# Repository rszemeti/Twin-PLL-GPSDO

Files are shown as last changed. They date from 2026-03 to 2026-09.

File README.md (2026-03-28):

# Twin PLL GPSDO

A dual-output GPS-disciplined reference project for Raspberry Pi Pico 2 (RP2350), with:
- Firmware for GPSDO control + PLL programming
- A desktop configuration tool (Windows-friendly)
- A PCB with 2 ADF4351's, GPS module and all the interface bits

## Who this is for
If you need a stable, GPS locked signal source for injection locking 1 or 2 crystal oscillators, or at a push a directly synthesised carrier up to 4.4 GHz.  

It has the advantage over some other units in that the two outputs are truly independently programmable. If you have a microwave transverter for example that needs injection locking and then a 144 to 28MHz converter, you often find that many units only allow the second output to be a fraction of the primary output, which may not produce thw 116 MHz you need. This unit has 2 synthesisers each of which can be programmed as desired.

## Features
- **Output 1 / Output 2 PLL**  Truly indpendent of each other
- **10MHz Auxilliary Output**  For driving other items, eg main radio.
- **Persistent settings** (ADF register writes are auto-committed to EEPROM)
- **Live status LEDs** (GPS fix/lock, satellites, DOP, alarm, lock states)
- **Windows configuration tool** with Main/Details/Tuning/About tabs

## RF output notes
- **Two outputs are fully independent**: each PLL output has its own register set and can be tuned separately.
- **Frequency range**: any frequency within the ADF4351 synthesizer output range is supported in software (approximately **34.375 MHz to 4.4 GHz**).
	- Practical usable range depends on your board layout, output network, filtering, and measurement method.
- **Resolution / step size**:
	- In **Integer-N**, tuning is quantized by $f_{PFD}/\text{OUTDIV}$.
	- With default settings (10 MHz ref, R=5, so $f_{PFD}=2$ MHz), Integer-N step is $2\text{ MHz}/\text{OUTDIV}$ (for example, 62.5 kHz at OUTDIV=32).
	- In **Fractional-N**, finer step sizes are possible (GUI default channel spacing is 1 Hz), but with fractional spurs/tradeoffs.
- **Phase-noise tradeoff**:
	- **Integer-N** is generally preferred for best close-in noise / cleaner spectrum when an exact frequency is possible.
	- **Fractional-N** gives finer frequency placement when exact Integer-N is not available, but may increase spur content.
- **Intended use guidance**:
	- Phase noise is typically **good enough for injection-locking crystal multipliers**.
	- It may **not** be good enough for all **direct multiplication** chains, depending on your multiplier stages and phase-noise budget.

## Repository layout
- `firmware/` – PlatformIO project for Pico 2
- `monitor/` – Python GUI configuration tool app
- `.github/workflows/` – release build automation
- `REFERENCE_LOCKING_README.md` – technical notes on GPS reference locking, PIO timing, interrupts, and timing/error budget

## Quick start (recommended)
### 1) Download a Release
From GitHub Releases, download:
- `Twin-PLL-GPSDO-<tag>.uf2` (firmware)
- `TwinPLLGPSDOMonitor-<tag>.exe` (Windows configuration tool)

### 2) Flash firmware (`.uf2`)
1. Put Pico 2 into BOOTSEL mode.
2. Copy the `.uf2` file to the mounted RP drive.
3. Board reboots automatically.

### 3) Run the configuration tool (`.exe`)
1. Start `TwinPLLGPSDOMonitor-<tag>.exe`.
2. Select COM port and click **Connect**.
3. Use **Set O/P 1** / **Set O/P 2** to configure outputs.

---

## Build from source
## Firmware
Prerequisites:
- Python 3.11+
- PlatformIO

Commands:
```bash
cd firmware
python -m platformio run
```
Upload (example COM port):
```bash
python -m platformio run -t upload --upload-port COM7
```

## Configuration tool (Python)
Prerequisites:
- Python 3.11+

Commands:
```bash
cd monitor
python -m venv .venv
.venv\Scripts\activate
pip install -r requirements.txt
python gpsdo_monitor.py
```

## Configuration tool usage notes
- **Main tab**: front-panel style status + output frequencies + output set buttons
- **Details tab**: logs, decoded registers, DAC/state details
- **About tab**: project links and author links

The configuration tool supports JSON command send for advanced/manual control.

## Persistence behavior
When a PLL/program command is applied:
- Registers are staged
- EEPROM auto-commit is performed in firmware
- On success, firmware emits a success event and the configuration tool shows **Device Updated**

## Releases and updates
On published release, GitHub Actions builds and attaches:
- Firmware UF2
- Configuration tool one-file EXE

So most users can update without local toolchains.

## Troubleshooting
- **Configuration tool cannot connect**: verify correct COM port and close other serial tools.
- **No lock / unstable GPS**: verify antenna visibility and allow warm-up time.
- **Upload issues on Windows**: retry BOOTSEL entry and ensure USB cable supports data.

## Author / links
- Robin Szemeti, G1YFG
- QRZ: https://www.qrz.com/db/G1YFG
- Blog: https://g1yfg.blogspot.com/
- Project repo: https://github.com/rszemeti/Twin-PLL-GPSDO

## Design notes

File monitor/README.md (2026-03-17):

GPSDO Configuration Tool

A minimal PySide6 GUI configuration tool that connects to the device over serial, parses JSON status lines, and displays key fields.

Full software manual:
- See `docs/MONITOR_USER_MANUAL.md` for complete usage, workflows, and troubleshooting.

Setup

To configure the unit, a simple GUI is available as a pre-built Windows .exe file Just download, connect your device over USB and run the program. You can configue the two fully independent outputs directly from the program. 

Updating the software on the unit itself is simply a question of powering it up ovr USB with the "reset" button pressed down and dragging a new .uf2 firmware file onto the folder that appears on your desktop.

Advanced

The adventurous may prefer to download the Python GUI sourcecode and run the GUI from its native Python source.

python -m venv .venv
.venv\Scripts\activate
pip install -r requirements.txt

Run

python gpsdo_monitor.py

Usage

- Select serial port and press Connect.
- The configuration tool displays firmware version, peripheral states, DAC value, ADF lock states, and logs raw/non-JSON lines.
- Send JSON commands from the **Advanced** tab send box (e.g. {"cmd":"dac","value":2048}).
- Use **Set PLL1 Register** or **Set PLL2 Register** to enter a target frequency and apply generated ADF4351 registers; popups preload from decoded live register values when available (otherwise fallback defaults are 10 MHz ref, R=5).
- Popup **Synth mode** options:
	- **Auto**: use Integer-N when exact, otherwise use Fractional-N.
	- **Integer-N only**: force integer synthesis.
	- **Fractional-N only**: force fractional synthesis for closest frequency.
- Popup **RF output power** lets you choose ADF4351 output power (-4, -1, +2, +5 dBm setting).
- Popup **Noise mode** lets you choose **Low noise** or **Low spur** register mode.
- Popup **Charge pump current** lets you choose the ADF4351 CP current code (0.31 mA to 5.00 mA).
- The firmware now auto-saves ADF registers to EEPROM when `program` is issued, so settings persist across reboot without a separate save step.
- **Discipliner Control (Advanced)** (Advanced tab) lets you read/apply runtime `avg_window_s`, `P gain`, and `I gain` via firmware JSON command `disc_ctrl`.
- Preset buttons (**Slow**, **Normal**, **Fast**) provide one-click loop tuning and immediately apply those values.
- Applied discipliner settings are persisted in firmware and restored after reboot.
- **Step Response...** in **Discipliner Control (Advanced)** opens a test tool that can run a timed DAC step, temporarily increase telemetry rate to 1 Hz, capture response samples, and export CSV.

ADF4351 register helper

- `adf4351_registers.py` contains a reusable `ADF4351RegisterCalculator` class.
- Use `solve(target_hz)` to generate `R0..R5` values from a reference/config.
- Use `decode_registers(regs, ref_hz)` and `verify_target(...)` to validate any existing register set before programming hardware.
- This is intended to avoid trusting unverified register words from external tools.

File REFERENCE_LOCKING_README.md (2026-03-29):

# Reference Locking Technical Notes

This is the technical companion to the main README. It describes how the
firmware actually locks the 10 MHz OCXO to GPS and what all the pieces do.

## 1) What the loop does

The whole point of the disciplining loop is to keep a local 10 MHz OCXO
tightly on frequency, steered by GPS 1PPS. Once the OCXO is disciplined,
it clocks both ADF4351 synthesisers.

In broad strokes:

1. Detect each GPS 1PPS rising edge.
2. Count how many 10 MHz cycles occurred during that one-second window.
3. Compute the integer count error: `edgesThisSec − 10,000,000`.
4. Keep a rolling ring buffer of the last N seconds of integer count
   errors and maintain a running sum.
5. Every second, divide the windowed sum by N to get the average count
   error in Hz (as a double), and feed that to the integrator which
   nudges the DAC (OCXO EFC voltage).
6. Only declare "locked" once the DAC output has been stable (not moving
   much) for long enough to be credible.

Here is the signal flow through the loop:

```mermaid
flowchart TD
    GPS[GPS 1PPS] --> PPS[PIO PPS capture ISR]
    OCXO[10 MHz OCXO] --> EDGE[PIO edge counter]
    EDGE --> PPS

    PPS --> OBS[Per-second observables
pulse count · integer count error Hz]

    OBS --> RING[Integer ring buffer
running sum of count errors]
    RING --> AVG[Average count error
windowSum / N  →  double Hz]
    AVG --> INT[Integrator
DAC -= gain × avg count error]
    INT --> DAC[DAC / EFC]
    DAC --> OCXO

    AVG --> LOCK[Lock detector
DAC stability over 60 s window]
    LOCK --> STATE[ACQUIRING / LOCKED / HOLDOVER]
    STATE -.-> INT

    EEPROM[Saved DAC from EEPROM] -.-> INT
```

---

## 2) How the measurement works

### 2.1 PPS capture

A PIO state machine watches the GPS 1PPS line. When it sees a rising
edge it fires `PIO0_IRQ_0`, which triggers the edge-counter snapshot
described below.

**Zero-jitter capture.** Because the PIO hardware reacts to the pin
within one PIO clock cycle (~6.67 ns at 150 MHz), no CPU interrupt
latency is involved in the timing-critical capture. A conventional ISR
would suffer variable delay while the CPU finishes its current
instruction, saves context, and vectors to the handler — this jitter
can easily be tens to hundreds of nanoseconds and would directly
corrupt the edge count. The PIO approach eliminates this entirely: the
state machine runs independently of the CPU, so the capture is
cycle-exact regardless of what the CPU is doing. Any count variability
observed is therefore real oscillator behaviour (thermal drift, EFC
settling, etc.) or GPS 1PPS edge quality, not measurement artefact.

We trust the GPS 1PPS to *be* one second — GPS 1PPS accuracy is
typically ±30 ns, which is far better than anything we could measure
on-chip. So the gate interval is simply one second by definition, and
the edge count over that gate *is* the OCXO frequency in Hz. No
division by a measured interval is needed or done.

### 2.2 Counting 10 MHz edges — the "counter around zero" model

The easiest way to think about the frequency measurement is this:

Imagine a virtual counter that starts at zero. Every rising edge of the
10 MHz OCXO **subtracts 1**. Every GPS 1PPS pulse **adds 10,000,000**.
If the oscillator is running at exactly 10 MHz, the counter stays at
zero — exactly 10 million edges arrive between each PPS, and the add
cancels the subtract perfectly. If the OCXO is running a little fast,
more than 10 million edges pile up and the counter drifts negative. If
it's a bit slow, fewer edges arrive and the counter drifts positive.

The value in the counter at any moment is the accumulated frequency
error in units of 10 MHz cycles. Over a multi-second window, summing
N one-second residuals gives the same number that a single free-running
counter would have reached — no edges are missed or double-counted, so
the two views are mathematically identical.

> **Implementation note:** the firmware doesn't literally maintain a
> running accumulated counter. Instead, a PIO state machine decrements
> its X register on every 10 MHz rising edge, and the PPS ISR snapshots
> X each second to compute the per-second delta
> (`edgesThisSec = prevX − currentX`). The one-second residual is then
> just `edgesThisSec − 10,000,000`. These integer residuals are stored
> in a ring buffer with a windowed `int64_t` running sum (bounded by
> window size × max per-second error, not an unbounded accumulation).
> The average over the window (`sum / N` as a `double`) is what feeds
> the integrator. The per-second unsigned subtraction of X handles
> 32-bit wrap correctly, and the windowed sum avoids any concern about
> unbounded growth, while preserving sub-ppb precision through the
> entire path.

From the per-second edge count, the frequency error is simply:

$$
error_{Hz} = N_{edges} - 10{,}000{,}000
$$

Because the PPS gate *is* one second, the edge count *is* the frequency
in Hz — no division required. The control loop works entirely in Hz
(integer count errors averaged to a `double`). A ppb value is also
computed for telemetry display but is **not** part of the control path:

$$
error_{ppb} = \frac{error_{Hz}}{10{,}000{,}000} \cdot 10^9 = error_{Hz} \times 100
$$

A **sanity gate** rejects any reading where the error exceeds ±50 kHz
(±0.5%). This catches partial first-second counts after a warm reset
(the PIO counter starts mid-PPS period and gets a nonsense edge count)
and cold OCXO startup where the crystal hasn't reached full amplitude
yet. Rejected readings are marked invalid so they never reach the
rolling average, the integrator, or the lock detector.

---

## 3) The control loop

The firmware maintains a rolling ring buffer of per-second **integer**
count errors (`edgesThisSec − 10,000,000`). A running `int64_t` sum
traces the ring so re-scanning is never needed. Every second, the
windowed sum is divided by the number of samples to produce an average
count error in Hz (as a `double`), and that value is passed to the
discipliner.

By keeping everything as exact integers until the final division, no
floating-point quantisation can create a dead zone — a single extra
edge in 128 seconds (0.0078 Hz) is faithfully represented.

The discipliner is a pure integrator (no proportional term). It adjusts
the DAC by `i_gain × avg_count_error` each second, where the averaging
window acts as a jitter filter without affecting the integrator's gain
units (DAC counts per Hz-error per update).

The loop runs in two modes:

- **Acquiring** — uses the base window (`DISC_AVERAGE_SECS`, default
  16 s) with the full I gain (`DISC_I_GAIN`, default 5.0) for fast
  pull-in.
- **Locked** — multiplies the window by `DISC_AVG_LOCKED_MULTIPLY`
  (currently ×4, giving 64 s) and reduces the gain by
  `DISC_I_GAIN_LOCKED_RATIO` (currently ×0.5, giving effective 2.5).
  Both changes happen simultaneously when lock is declared. The longer
  window plus the lower gain together narrow the loop bandwidth
  considerably, so normal 1PPS jitter doesn't keep jiggling the DAC.

When transitioning from ACQUIRING to LOCKED, the ring buffer and running
sum are zeroed so the locked-mode window starts clean without stale
pull-in residuals.

If lock is lost the short window and full gain kick back in.

On power-up the firmware reads the last-known DAC value from EEPROM and
seeds the integrator with it, so the OCXO starts very close to where it
left off rather than hunting from the middle of the DAC range.

The DAC output is hard-clamped to `DAC_MIN..DAC_MAX` so the integrator
can never rail.

### State machine

| State | Meaning |
|---|---|
| WARMUP | Waiting for GPS fix and initial settling |
| ACQUIRING | Loop is running, not yet meeting lock criteria |
| LOCKED | Error is small and DAC has settled — full lock |
| HOLDOVER | GPS lost, DAC is frozen at last good value |
| FREERUN | No GPS available, running open-loop |

---

## 4) Telemetry

The firmware sends two kinds of JSON messages over the serial link.

**OCXO event** (every second) — carries the raw measurement:
`pulse_count`, `measured_hz`, `freq_error_ppb`.

**Status** (periodic) — carries the full system snapshot: GPS fix,
DAC value, ADF lock-detect states, discipliner state, plus averaging
visibility fields (`disc_avg_window_s`, `disc_count_err`,
`disc_avg_count_err`, `count_err_sum`) so the monitor app can show
what the loop is doing.

---

## 5) Timing resolution

The PIO edge counter runs at the system clock (150 MHz, ~6.67 ns per
tick), but that's just the speed at which PIO executes its instructions
— the actual measurement resolution comes from counting complete 10 MHz
edges over a one-second gate. The gate itself is GPS 1PPS, which we
trust to be exactly one second (GPS 1PPS is accurate to ~30 ns).

So the frequency resolution is ±1 Hz per single-second gate (one edge
more or less), and averaging over several seconds smooths that further.

---

## 6) Why PIO edge counting?

Earlier firmware versions tried various approaches. The current PIO
counting method won out because it:

- counts every single 10 MHz edge without burning CPU time,
- avoids per-edge interrupts entirely (PIO does it in hardware),
- gives a clean integer count each second,
- pairs naturally with multi-second averaging for sub-ppb control.

---

## 7) ADF lock detect

The two ADF4351 PLLs have their own lock-detect pins (`ADF1_LD_PIN`,
`ADF2_LD_PIN`). These are read directly by the firmware and drive the
status LEDs, alarm logic, and the lock fields in telemetry JSON. They
are independent of the OCXO disciplining lock — they tell you whether
each synthesiser PLL is happy with its own loop.

---

## 8) How lock detection actually works

Frequency-error readings are inherently noisy — GPS 1PPS jitter can
produce occasional outliers of ±1300 ppb (±13 Hz) even when the OCXO is
perfectly stable. Trying to judge lock from the frequency error alone
turns out to be unreliable because those outliers poison any simple
threshold or average.

What *does* tell us whether the loop has converged is the DAC output.
When the integrator has found the right EFC voltage, the DAC value
stops moving — it just sits there, with small corrections that don't
add up to much. If the OCXO is genuinely drifting, the DAC has to
chase it and the value trends steadily in one direction.

The firmware keeps a ring buffer of the last 60 per-second DAC
snapshots and looks at the range (max − min) over that window:

- **Lock is entered** when the DAC range over 60 seconds is
  ≤ `DISC_LOCK_DAC_RANGE_ENTER` (currently 30 counts) and the DAC is
  not railed at `DAC_MIN` or `DAC_MAX`.
- **Lock is dropped** when the range exceeds
  `DISC_LOCK_DAC_RANGE_EXIT` (currently 50 counts).

The hysteresis between the enter and exit thresholds prevents the state
from flickering on borderline noise.

The lock buffer is only populated while the discipliner is in ACQUIRING
or LOCKED state — during FREERUN or WARMUP a constant DAC value would
otherwise fill the buffer and falsely declare lock. If lock is lost the
buffer is reset so the full 60-second dwell is required again.

Because the buffer must be full (60 seconds of stable DAC data) before
lock is even considered, this naturally prevents premature lock on cold
start or warm restart — the loop has to have converged and settled for
a solid minute before the firmware will claim it's locked.

---

## 9) Quick reference

| What | How |
|---|-----|
| PPS edge detection | PIO state machine, cycle-exact hardware capture (no ISR jitter) |
| Frequency measurement | PIO edge count of 10 MHz per 1PPS gate |
| Error signal | Integer count error per second → ring buffer → average (double Hz) |
| Control update rate | Every second (rolling average) |
| Loop type | Pure integrator (no P term), gain in DAC counts per Hz-error |
| I gain | Acquiring: 5.0, Locked: 2.5 (×0.5 ratio) |
| Averaging window | Acquiring: 16 s, Locked: 16 × 4 = 64 s |
| DAC persistence | Saved to EEPROM, restored on restart |
| Lock criteria | 60 s DAC ring buffer: range ≤ 30 counts to enter, > 50 to exit |
| Gain management | Acquiring: full gain + base window; Locked: gain ×0.5 + window ×4 (both applied simultaneously) |
| Zero-on-lock-entry | Ring buffer cleared on ACQUIRING → LOCKED transition |

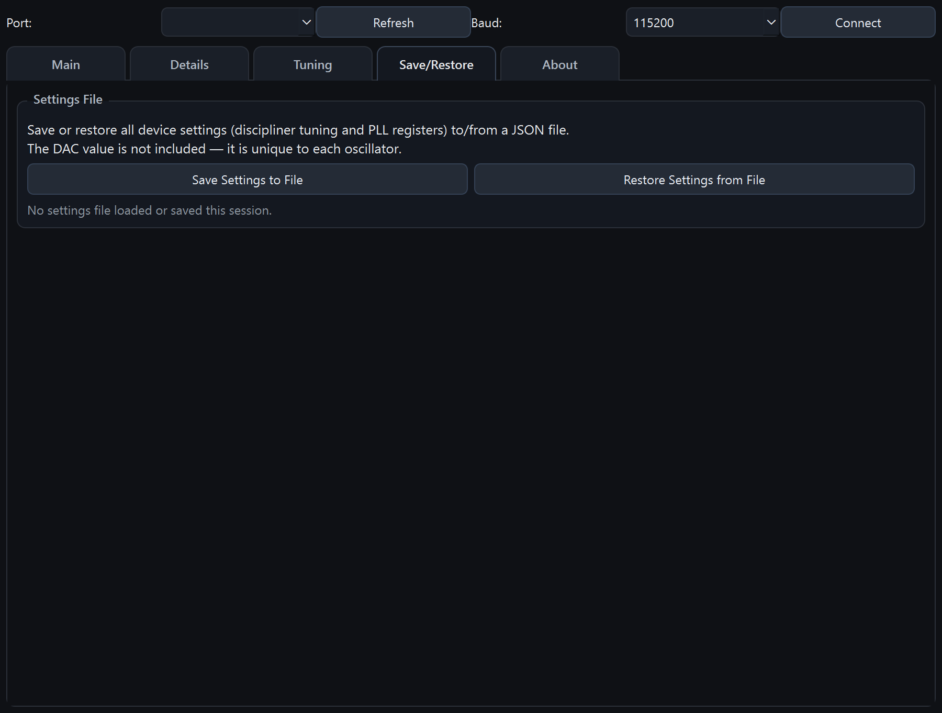
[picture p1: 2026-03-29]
docs/screenshots/07-saverestore-live.png

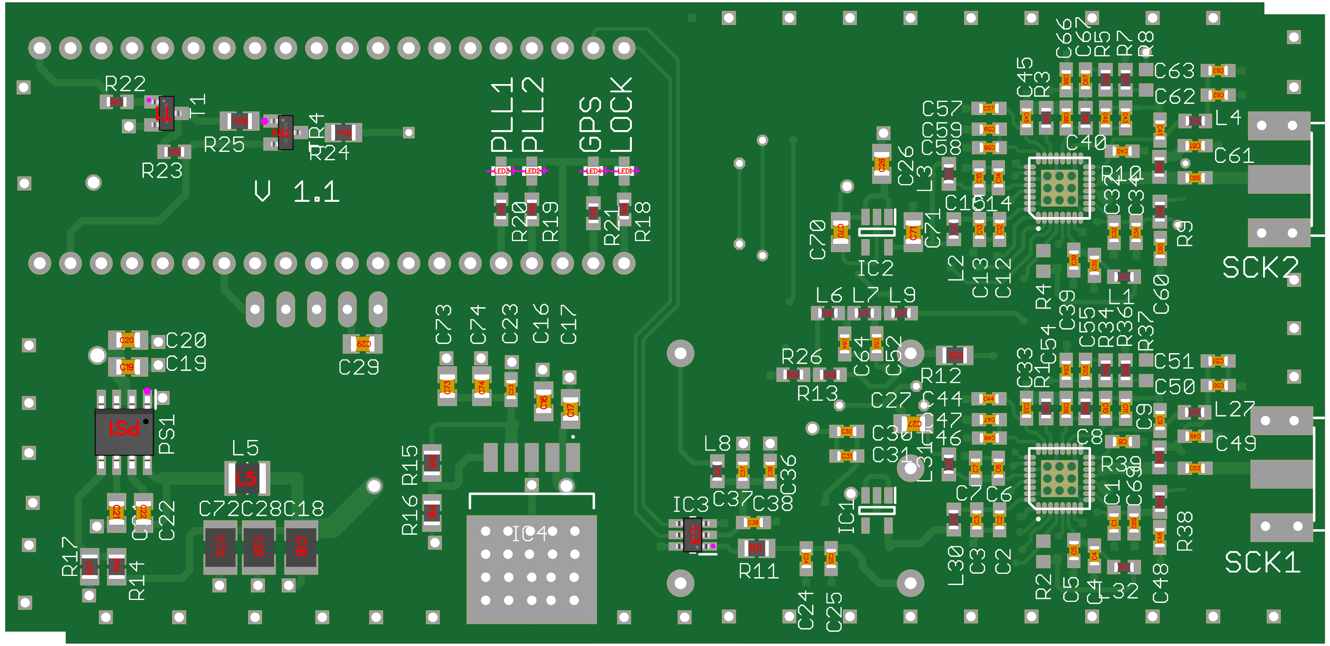
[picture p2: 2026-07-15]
PCB/Gerbers/99777f261f3146b595dd99c6c57098c4_T.png

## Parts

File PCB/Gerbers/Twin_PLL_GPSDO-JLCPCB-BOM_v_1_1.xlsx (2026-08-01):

Comment | Designator | Footprint | JLCPCB Part #（optional）
100pF | C1, C2, C5, C6, C8, C10, C12, C14, C32, C33, C39, C40, C42, C45, C46, C48, C49, C53, C58, C60, C61, C65 | C0603
22uF | C18, C28, C72 | C1210
10uF | C20, C74 | C0805
1uF | C21 | C0805
100nF | C3, C4, C7, C9, C11, C13, C15, C23, C24, C30, C34, C35, C37, C38, C41, C43, C44, C47, C50, C57, C59, C62, C69 | C0603
100nF | C17, C19, C22, C26, C27, C29, C70, C71, C73 | C0805
1uF | C25, C31, C36, C51, C63 | C0603
1nF | C52, C64 | C0603
3.3nF | C54, C66 | C0603
47nF | C55, C67 | C0603
1.5nF | C56, C68 | C0603
ADP151WAUJZ-1.8-R7 | IC1, IC2 | SOT95P280X100-5N
MCP4725A0T-E_CH | IC3 | SOT95P270X145-6N
LT1963AEQ-2.5#PBF | IC4 | LT1963AEQ25PBF
DFE322512F-3R3M=P2 | L5 | 1277ASH100MP2
100nH | L1, L2, L3, L4, L6, L7, L8, L9, L27, L30, L31, L32 | R0603
 | LED1, LED2, LED3, LED4 | CHIPLED_0603
CTI_OSC | OSC1 | CTI_OSC
LMR33630ADDA | PS1 | SOIC127P600X170-9N
5.1K | R1, R3 | R0603
10K | R2, R4 | R0603
1K | R11, R14, R15, R16, R17 | R0805
100R | R12 | R0805
3.3K | R13 | R0603
1K | R23 | R0603
330R | R24 | R0805
10K | R25 | R0805
4.7K | R26 | R0603
330R | R5, R18, R19, R20, R21, R22, R34 | R0603
680R | R6, R35 | R0603
0R | R7, R36 | R0603
NF | R8, R37 | R0603
51R | R9, R10, R38, R39 | R0603
SMA-142-0701-871/876 | SCK1, SCK2 | J502-ND-142-0701-871/876
BC847 | T1 | SOT23
SI2309 | TR4 | SOT23
 | U1 | PICO-PKG-TH-STD
ADF4351BCPZ | U2, U3 | QFN50P500X500X100-33V2N
GPS | U$2 | GPS

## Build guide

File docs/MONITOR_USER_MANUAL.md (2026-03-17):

# Twin PLL GPSDO Configuration Tool — User Manual

**Release Version:** `{{RELEASE_TAG}}`

This manual covers the desktop configuration tool software (`monitor/gpsdo_monitor.py` / packaged EXE).

## 1. What the monitor does

The configuration tool is the control and visibility front-end for your Twin PLL GPSDO firmware.

You can:
- connect to the device over serial,
- view live lock/health telemetry,
- set output frequency for PLL1 and PLL2,
- push raw ADF4351 registers,
- inspect decoded register state and JSON logs,
- confirm GUI build version in About.

## 2. Start-up

### 2.1 Connect
1. Launch the configuration tool.
2. Select the correct COM port.
3. Select baud (normally `115200`).
4. Click **Connect**.

After connecting, the configuration tool automatically requests device info and ADF register snapshots.

### 2.2 If connection fails
- Verify the COM port is correct.
- Close other terminal/serial apps that may hold the port.
- Confirm firmware is running and emitting JSON status.

---

## 3. UI overview

The application has four main tabs:
- **Main**
- **Details**
- **Advanced**
- **About**

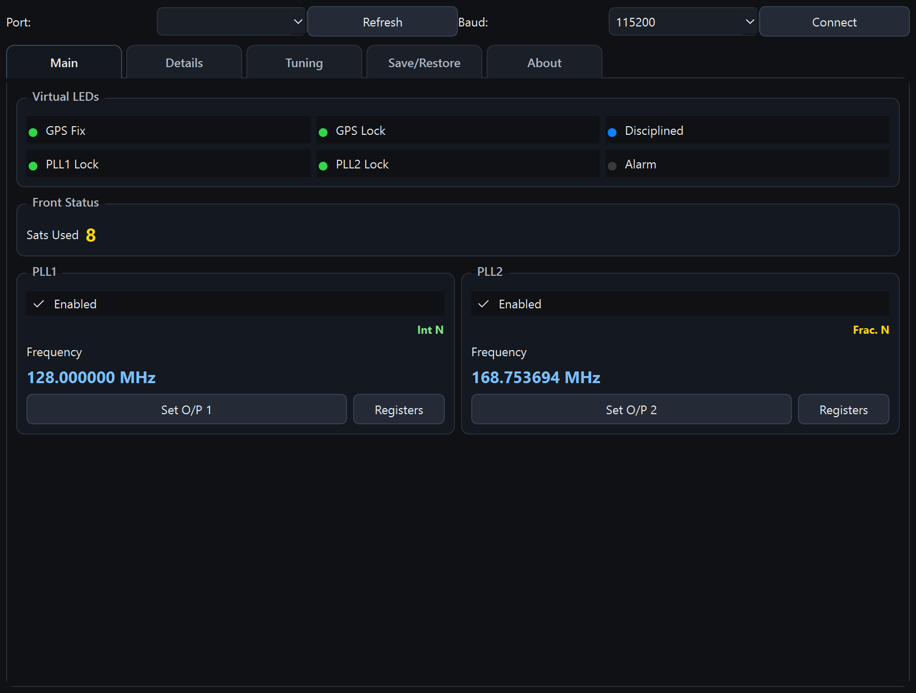
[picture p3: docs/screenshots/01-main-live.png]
Main tab


Screenshot source:
- **PLL1** with **Set O/P 1** and **Registers**
- **PLL2** with **Set O/P 2** and **Registers**

The frequency text in each card is decoded from live register readback.
Each PLL card also shows a top-right synthesis mode badge from live register decode: **Int N** (green) or **Frac. N** (yellow).
In this manual screenshot set, the Main view intentionally shows PLL1 as a clean Integer-N example and PLL2 as a clearly Fractional-N example.

### 4.2 Front Status
- GPS Fix
- GPS Lock
- Disciplined
- ADF1 Lock
- ADF2 Lock

### 7.5 Discipliner Control
The Advanced tab includes runtime loop controls:
- **Average window (s)**
- **P gain**
- **I gain**

Use **Refresh** to read current firmware values, and **Apply** to send updates without rebooting.
Preset buttons (**Slow**, **Normal**, **Fast**) provide one-click tuning profiles and apply immediately.
Applied values are saved in firmware persistent storage and restored on reboot.

### 7.6 Step Response Tool
Use **Step Response...** in **Discipliner Control (Advanced tab)** to open the step test dialog.

The tool can:
- apply a timed DAC step (baseline then step),
- optionally use near-open-loop gains for the test,
- temporarily set status telemetry to 1 Hz,
- capture response samples,
- export captured data to CSV.

Step-test temporary loop changes are applied in non-persistent mode, so they are not written to EEPROM.

- green/red used for good/bad lock-type status,
- alarm flashes if firmware reports flash alarm condition.

---

## 5. Setting PLL frequency (calculated mode)

Use this for normal operation.

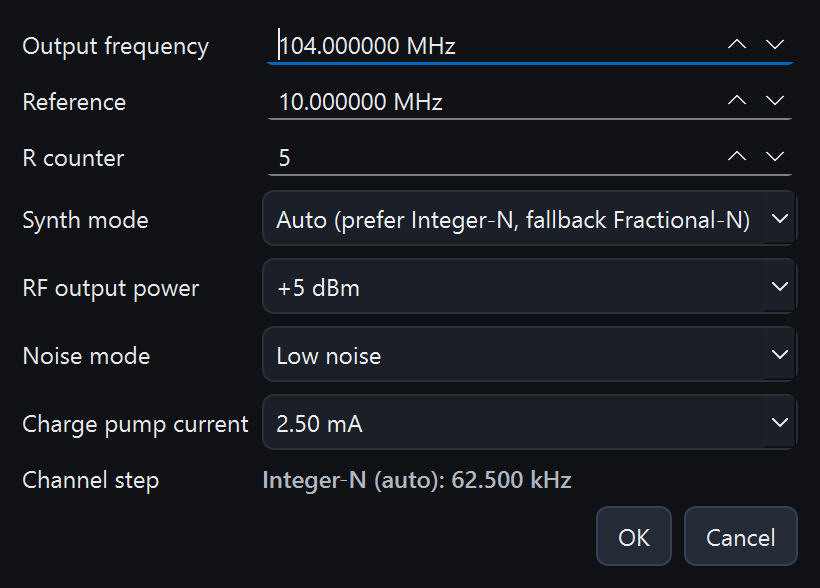
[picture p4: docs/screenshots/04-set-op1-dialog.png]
Set O/P 1 dialog


### 5.1 Set O/P 1
1. Click **Set O/P 1**.
2. Enter desired output frequency and reference settings.
3. Choose synthesis mode:
   - Auto (prefer Integer-N, fallback Fractional-N)
   - Integer-N only
   - Fractional-N only
4. Check the read-only **Channel step** line to see effective tuning resolution for the current reference/R/mode combination.
5. Optionally tune RF power / noise mode / charge pump current.
6. Click OK to send computed `set_all` registers and program the device.

### 5.2 Set O/P 2
Same process as PLL1.

> PLL2 workflow is intentionally identical to PLL1.

---

## 6. Raw register programming (advanced)

Use this when you already have exact register words.

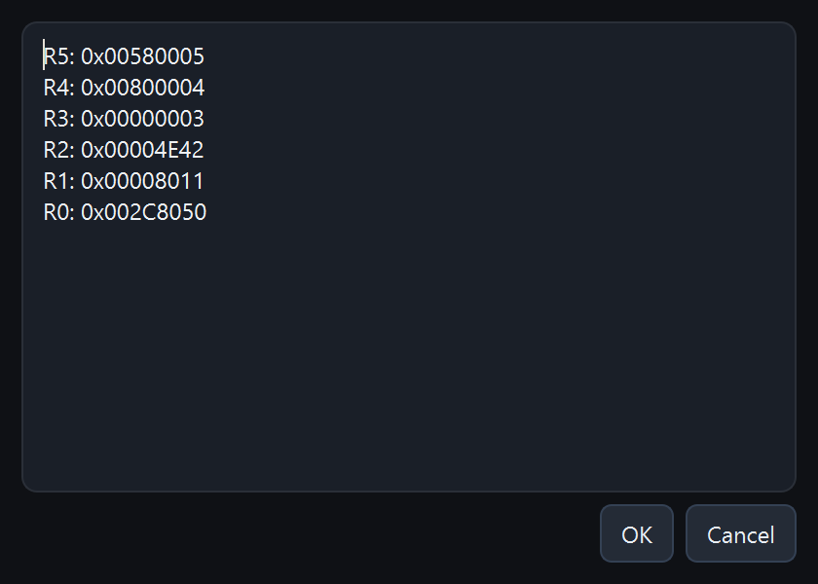
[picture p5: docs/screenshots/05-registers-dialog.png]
Registers dialog


### 6.1 Open raw dialog
- Click **Registers** on PLL1 or PLL2 card.

### 6.2 Input format
Enter six 32-bit hex words in **R5..R0** order.

Accepted forms include:
- `0x00580005`
- `R5: 0x00580005`
- comma-separated values

The configuration tool validates count and range, then maps to firmware `R0..R5` payload order automatically.

### 6.3 Program behavior
On OK, monitor sends:
- `cmd`: `adf1` or `adf2`
- `action`: `set_all`
- `regs`: six values
- `program`: `true`

Firmware then applies and (if enabled) persists settings.

---

## 7. Details tab

The Details tab is for deep visibility and manual control.

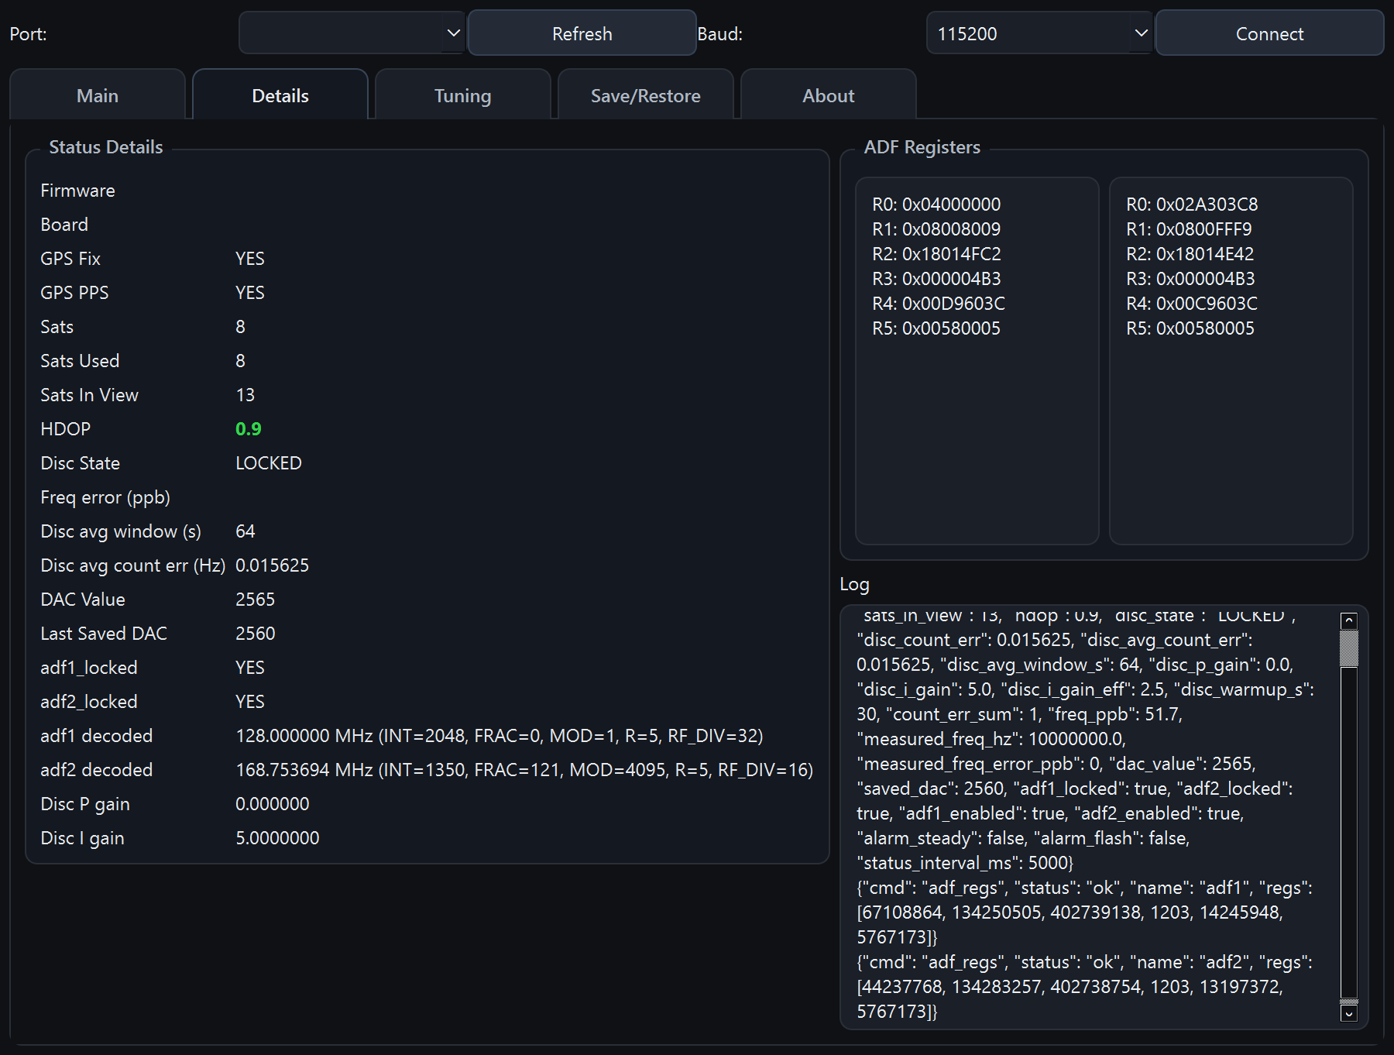
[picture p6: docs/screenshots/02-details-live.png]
Details tab


### 7.1 Status Details panel
Shows telemetry such as:
- Firmware version
- Board
- GPS fix / PPS
- Satellites used/in-view
- HDOP (with color coding)
- Disciplined state
- Phase error
- Averaging window and averaged phase
- DAC value
- ADF lock states
- Decoded ADF outputs

### 7.2 ADF Registers panel
Displays current register words for ADF1 and ADF2.

### 7.3 Log panel
Shows:
- firmware JSON events,
- warnings/errors,
- command TX lines,
- non-periodic operational events.

### 7.4 Send JSON box (Advanced tab)
Manual command entry for advanced operation.

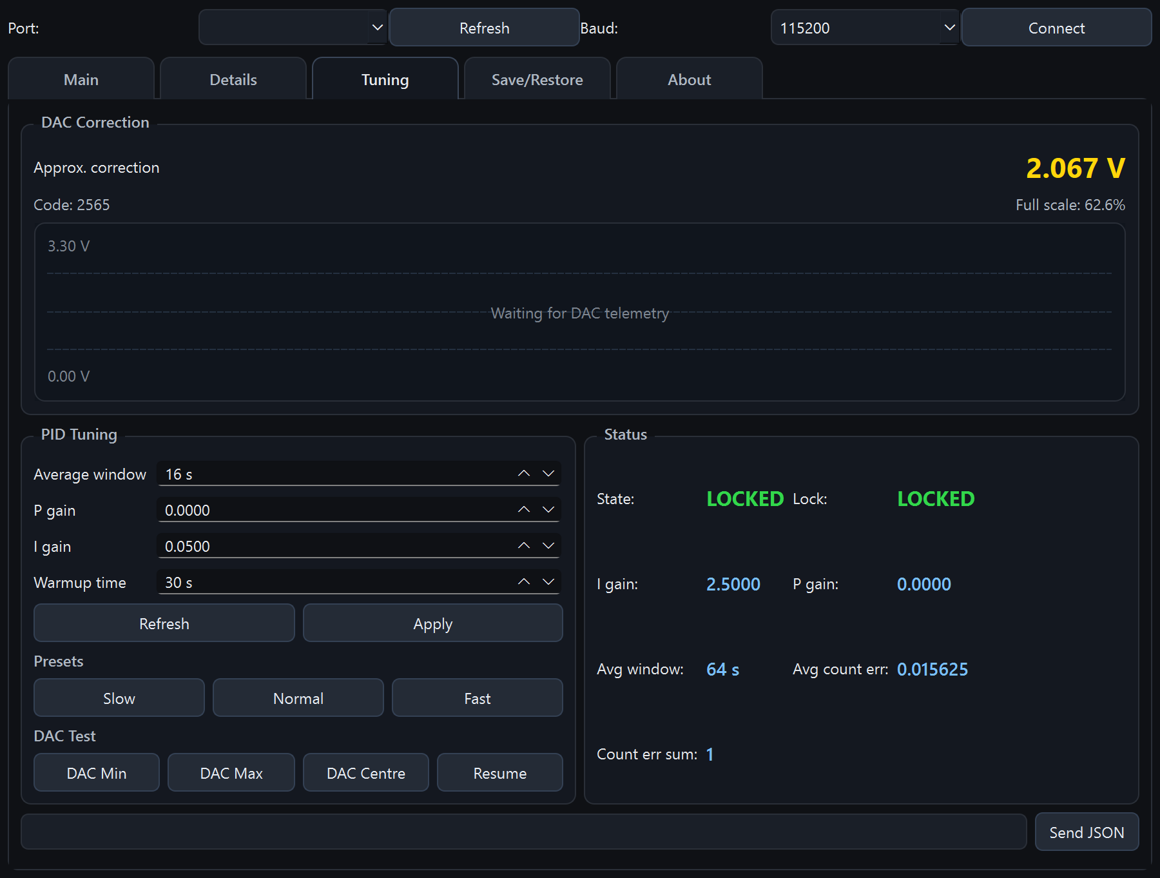
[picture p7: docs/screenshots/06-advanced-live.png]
Advanced tab


Example:
- `{\"cmd\":\"dac\",\"value\":2048}`

---

## 8. About tab

The About tab contains:
- project links,
- author links,
- **GUI Version** (the monitor build version).

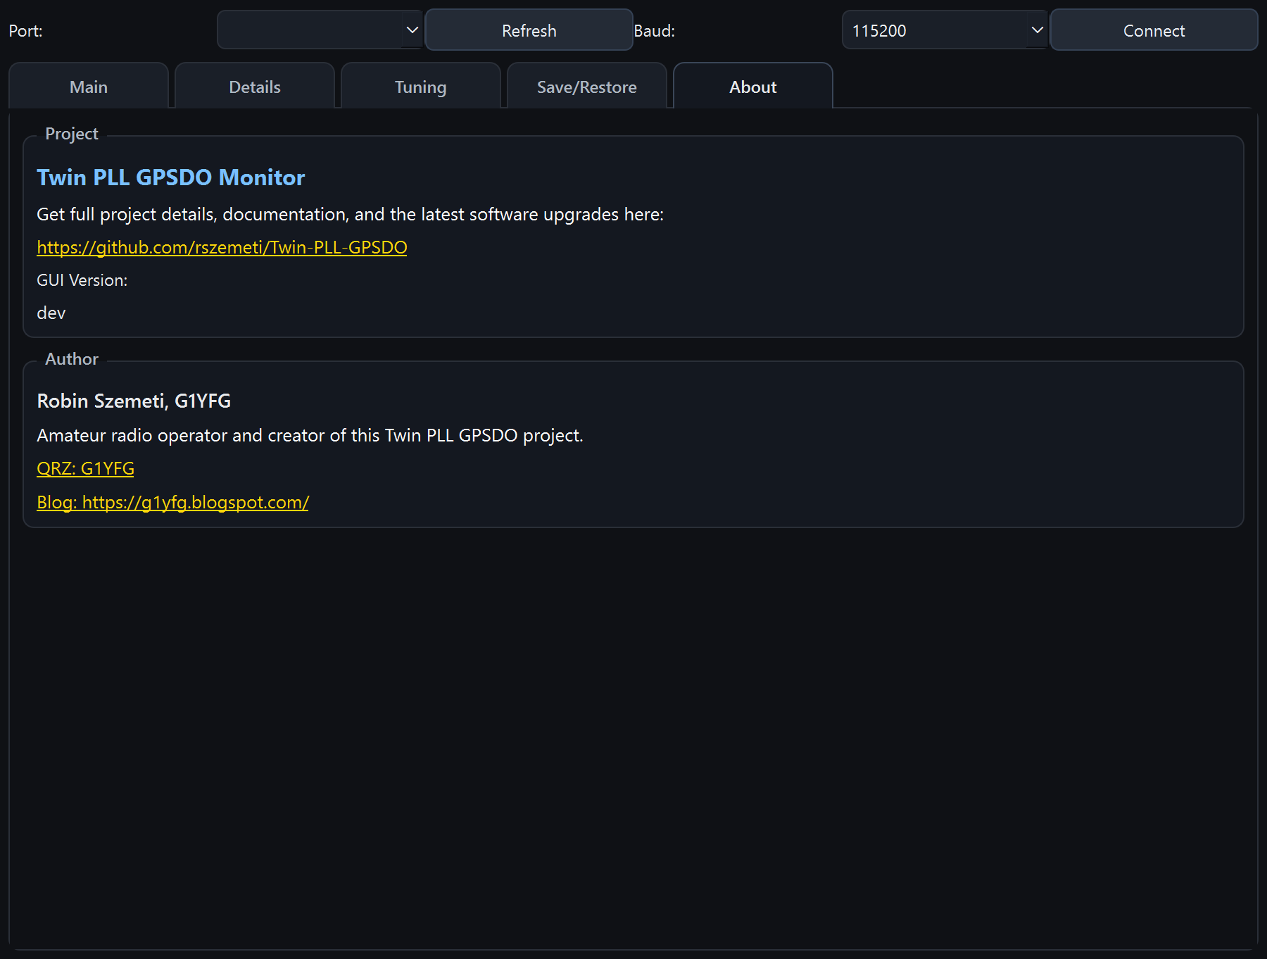
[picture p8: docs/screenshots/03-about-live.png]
About tab


Important distinction:
- About shows GUI version (local app build),
- device firmware version is shown in Details.

---

## 9. EEPROM/write success behavior

When firmware confirms successful EEPROM write, the configuration tool shows a **Device Updated** popup and logs the associated JSON event.

---

## 10. Practical operating flow

Recommended daily flow:
1. Connect.
2. Check Main LEDs (GPS, lock, alarm).
3. Set PLL1 and/or PLL2 using **Set O/P**.
4. Use **Registers** only for explicit register workflows.
5. Confirm status/logs in Details.

---

## 11. Troubleshooting

### 11.1 No live updates
- Verify serial connection and baud.
- Confirm firmware is outputting JSON status.

### 11.2 Set O/P does nothing
- Check connection state first.
- Watch log panel for TX failure or firmware error response.

### 11.3 Raw register dialog rejects input
- Ensure exactly 6 words are provided.
- Ensure values are valid 32-bit hex.
- Ensure input order is R5..R0.

### 11.4 LED states look inconsistent
- Wait for GPS to settle after startup.
- Check Details values (`gps_fix`, `gps_pps`, ADF lock fields, alarm flags).

---

## 12. Notes for release artifacts

In release builds:
- About → GUI Version reflects release tag.
- Firmware `info` reports firmware version tag.

For local dev runs, GUI version defaults to `dev` unless build metadata is injected.

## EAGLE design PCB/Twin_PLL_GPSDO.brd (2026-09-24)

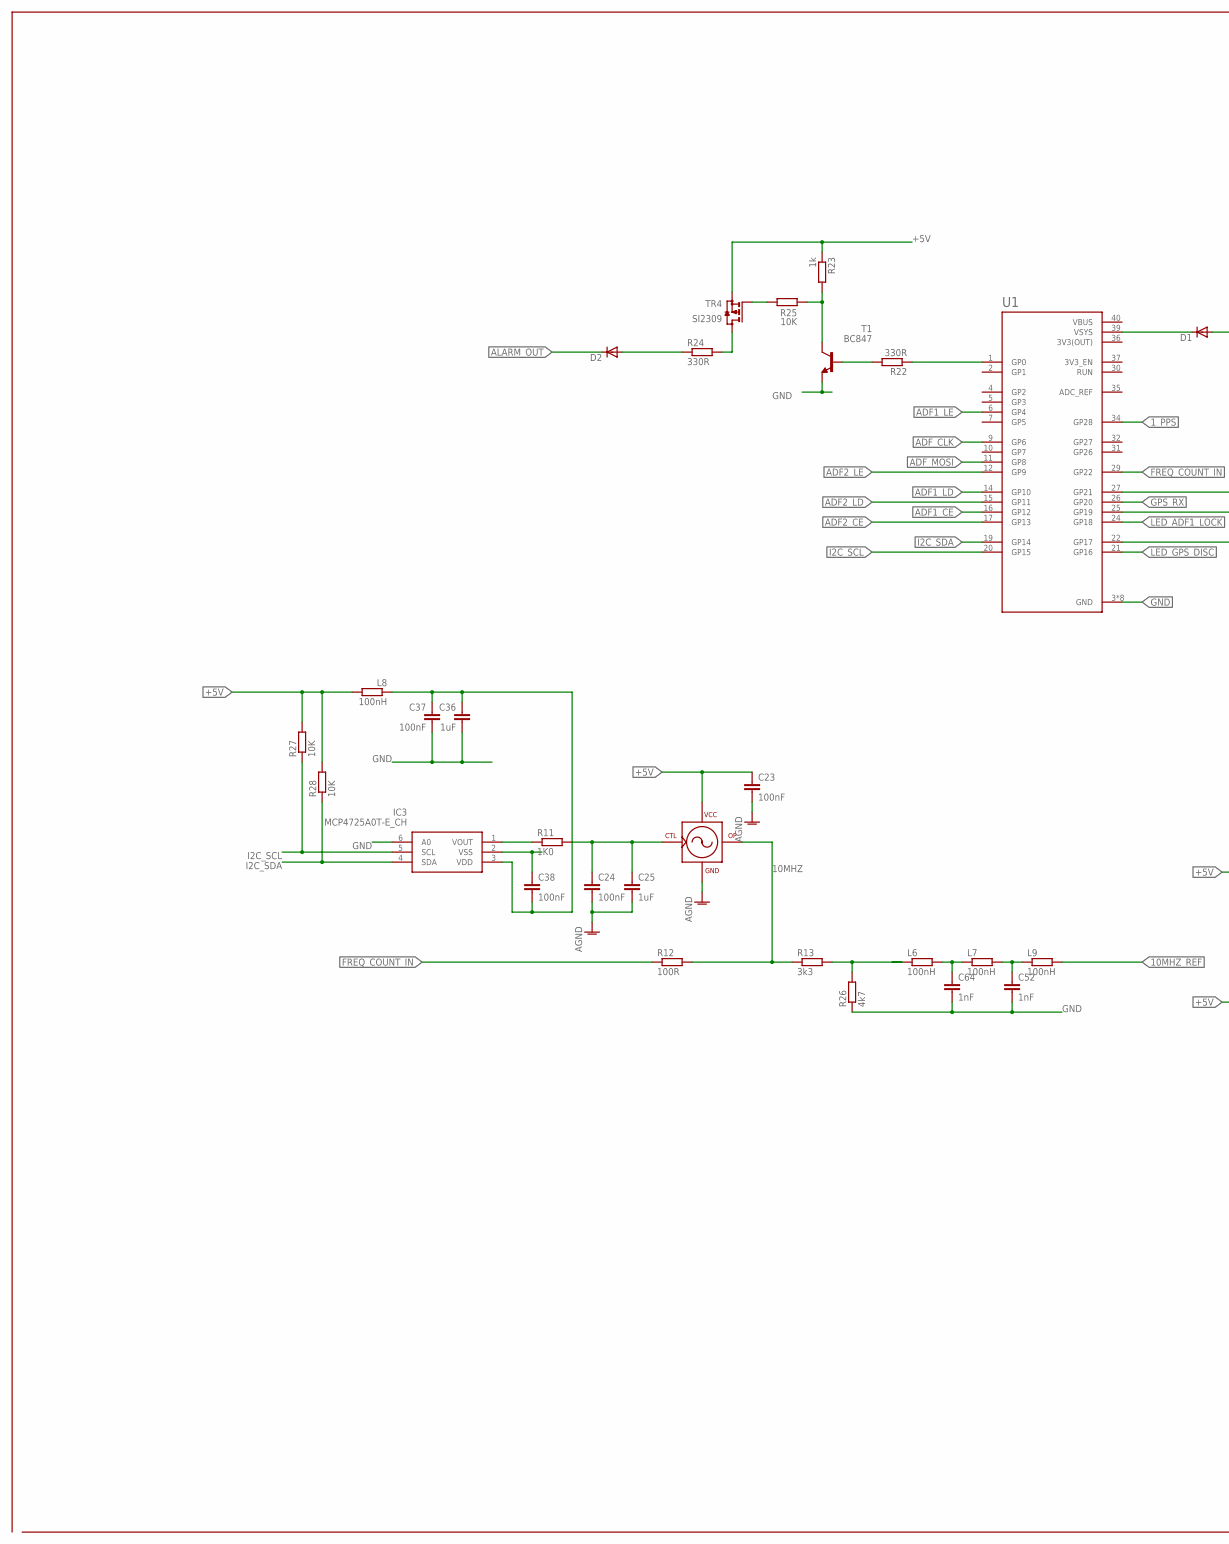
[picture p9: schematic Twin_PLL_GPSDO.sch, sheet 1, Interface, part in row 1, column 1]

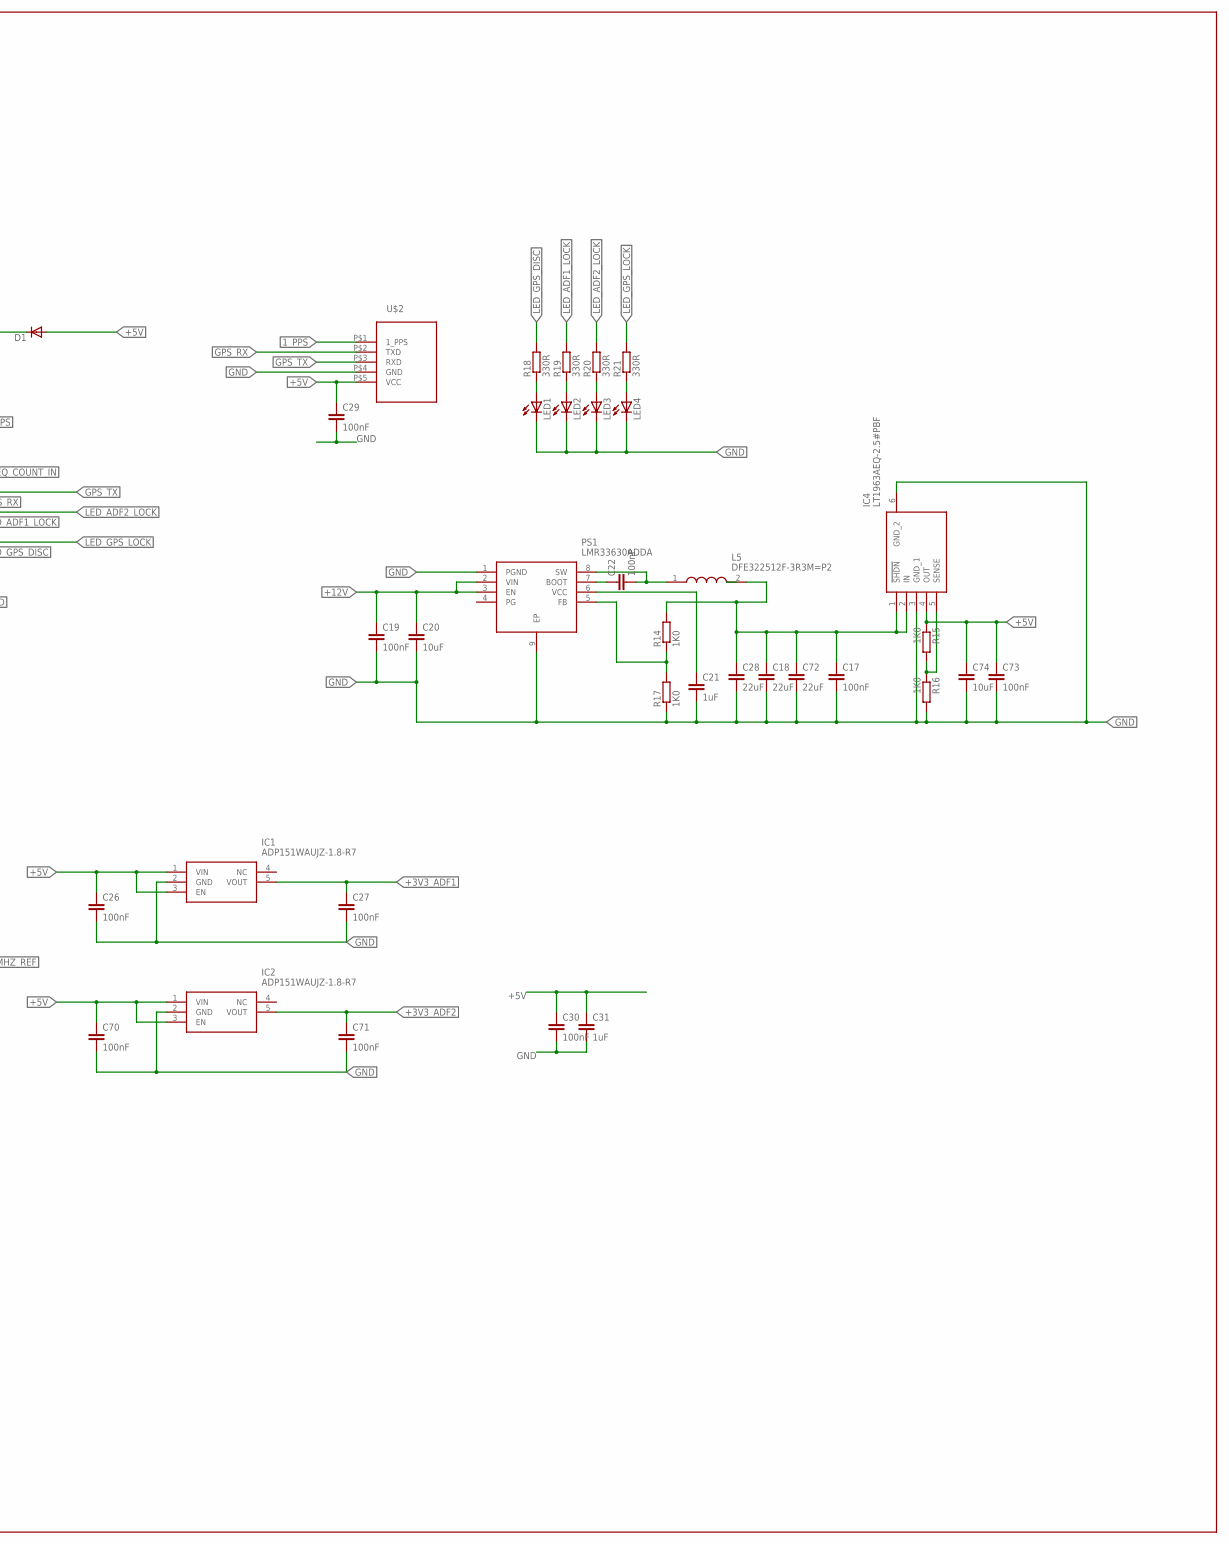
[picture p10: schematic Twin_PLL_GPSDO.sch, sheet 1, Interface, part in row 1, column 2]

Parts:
C17, C19, C22, C26, C27, C29, C70, C71, C73: 100nF; C0805
C18, C28, C72: 22uF; C1210
C20, C74: 10uF; C0805
C21: 1uF; C0805
C23, C24, C30, C37, C38: 100nF; C0603
C25, C31, C36: 1uF; C0603
C52, C64: 1nF; C0603
D1, D2: DIODE-SOD123; SOD123
IC1, IC2: ADP151WAUJZ-1.8-R7; SOT95P280X100-5N
IC3: MCP4725A0T-E_CH; SOT95P270X145-6N
IC4: LT1963AEQ-2.5#PBF; LT1963AEQ25PBF
L5: DFE322512F-3R3M=P2; 1277ASH100MP2; FARNELL_OC 2871467
L6, L7, L8, L9: 100nH; R0603
LED1, LED2, LED3, LED4: LEDCHIPLED_0603; CHIPLED_0603
OSC1: CTI_OSC
PS1: LMR33630ADDA; SOIC127P600X170-9N
R11, R14, R15, R16, R17: 1K0; R0805
R12: 100R; R0805
R13: 3k3; R0603
R18, R19, R20, R21, R22: 330R; R0603
R23: 1k; R0603
R24: 330R; R0805
R25: 10K; R0805
R26: 4k7; R0603
R27, R28: 10K; R0603
T1: BC847; SOT23
TR4: SI2309; SOT23
U1: RASPBERRY_PICO-NO_DEBUGTH; PICO-PKG-TH-STD
U$2: GPS

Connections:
1_PPS: U1.34 (GP28), U$2.P$1 (1_PPS)
3V3(OUT): U1.36 (3V3(OUT))
10MHZ: OSC1.OUT (OP), R12.2, R13.1
10MHZ_REF: L9.2; also elsewhere on the board
+3V3_ADF1: C27.1, IC1.5 (VOUT); also elsewhere on the board
+3V3_ADF2: C71.1, IC2.5 (VOUT); also elsewhere on the board
+5V: C23.1, C26.1, C29.1, C30.1, C31.1, C70.1, C73.1, C74.1, D1.A, IC1.1 (VIN), IC1.3 (EN), IC2.1 (VIN), IC2.3 (EN), IC4.4 (OUT), L8.2, OSC1.VCC, R15.1, R23.1, R27.2, R28.2, TR4.2 (S), U$2.P$5 (VCC)
+12V: C19.1, C20.1, PS1.2 (VIN), PS1.3 (EN)
ADF1_CE: U1.16 (GP12); also elsewhere on the board
ADF1_LD: U1.14 (GP10); also elsewhere on the board
ADF1_LE: U1.6 (GP4); also elsewhere on the board
ADF2_CE: U1.17 (GP13); also elsewhere on the board
ADF2_LD: U1.15 (GP11); also elsewhere on the board
ADF2_LE: U1.12 (GP9); also elsewhere on the board
ADF_CLK: U1.9 (GP6); also elsewhere on the board
ADF_MOSI: U1.11 (GP8); also elsewhere on the board
ALARM_OUT: D2.C
ALARM_PIN: R22.1, U1.1 (GP0)
AVDD: C36.1, C37.1, C38.2, IC3.3 (VDD), L8.1
FREQ_COUNT_IN: R12.1, U1.29 (GP22)
GND: C17.2, C18.2, C19.2, C20.2, C21.2, C23.2, C24.2, C25.2, C26.2, C27.2, C28.2, C29.2, C30.2, C31.2, C36.2, C37.2, C38.1, C52.2, C64.2, C70.2, C71.2, C72.2, C73.2, C74.2, IC1.2 (GND), IC2.2 (GND), IC3.2 (VSS), IC3.6 (A0), IC4.3 (GND_1), IC4.6 (GND_2), LED1.C, LED2.C, LED3.C, LED4.C, OSC1.GND, PS1.1 (PGND), PS1.9 (EP), R16.2, R17.1, R26.1, T1.2 (E), U1.3 (GND), U1.8 (GND), U1.13 (GND), U1.18 (GND), U1.23 (GND), U1.28 (GND), U1.33 (GND), U1.38 (GND), U$2.P$4 (GND); also elsewhere on the board
GPS_RX: U1.26 (GP20), U$2.P$2 (TXD)
GPS_TX: U1.27 (GP21), U$2.P$3 (RXD)
I2C_SCL: IC3.5 (SCL), R27.1, U1.20 (GP15)
I2C_SDA: IC3.4 (SDA), R28.1, U1.19 (GP14)
LED_ADF1_LOCK: R19.2, U1.24 (GP18)
LED_ADF2_LOCK: R20.2, U1.25 (GP19)
LED_GPS_DISC: R18.2, U1.21 (GP16)
LED_GPS_LOCK: R21.2, U1.22 (GP17)
unnamed: IC3.1 (VOUT), R11.1
unnamed: R23.2, R25.2, T1.3 (C)
unnamed: L6.1, R13.2, R26.2
unnamed: LED1.A, R18.1
unnamed: R22.2, T1.1 (B)
unnamed: IC4.5 (SENSE), R15.2, R16.1
unnamed: PS1.5 (FB), R14.1, R17.2
unnamed: C24.1, C25.1, OSC1.REF (CTRL), R11.2
unnamed: C21.1, PS1.6 (VCC)
unnamed: C22.1, PS1.7 (BOOT)
unnamed: C22.2, L5.1, PS1.8 (SW)
unnamed: C17.1, C18.1, C28.1, C72.1, IC4.1 (!SHDN), IC4.2 (IN), L5.2, R14.2
unnamed: LED2.A, R19.1
unnamed: LED3.A, R20.1
unnamed: LED4.A, R21.1
unnamed: D1.C, U1.39 (VSYS)
unnamed: C64.1, L6.2, L7.1
unnamed: R25.1, TR4.1 (G)
unnamed: C52.1, L7.2, L9.1
unnamed: D2.A, R24.1
SWITCH: R24.2, TR4.3 (D)
VBUS: U1.40 (VBUS)

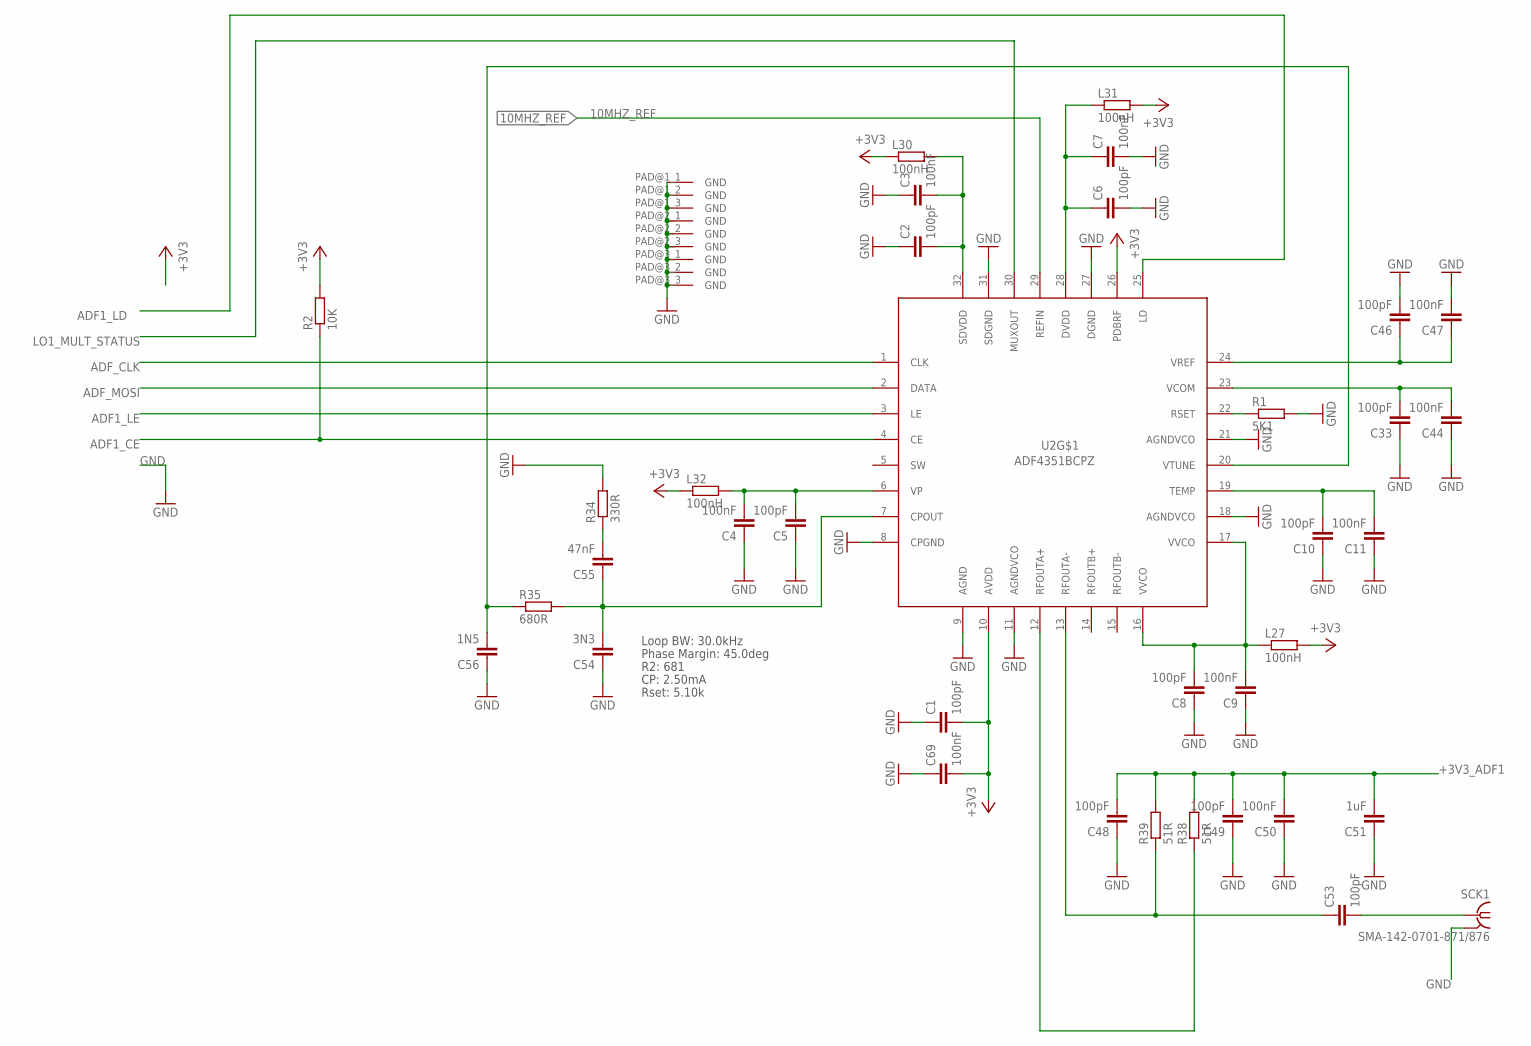
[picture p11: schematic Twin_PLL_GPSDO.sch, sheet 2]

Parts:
C1, C2, C5, C6, C8, C10, C33, C46, C48, C49, C53: 100pF; C0603
C3, C4, C7, C9, C11, C44, C47, C50, C69: 100nF; C0603
C51: 1uF; C0603
C54: 3N3; C0603
C55: 47nF; C0603
C56: 1N5; C0603
L27, L30, L31, L32: 100nH; R0603
R1: 5K1; R0603
R2: 10K; R0603
R34: 330R; R0603
R35: 680R; R0603
R38, R39: 51R; R0603
SCK1: SMA-142-0701-871/876; J502-ND-142-0701-871/876; MPN 142-0701-871
U2: ADF4351BCPZ; QFN50P500X500X100-33V2N

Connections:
10MHZ_REF: U2.29 (REFIN); also elsewhere on the board
+3V3_ADF1: C1.2, C48.2, C49.2, C50.2, C51.2, C69.2, L27.2, L30.1, L31.2, L32.1, R2.2, R38.2, R39.2, U2.10 (AVDD), U2.26 (PDBRF); also elsewhere on the board
ADF1_CE: R2.1, U2.4 (CE); also elsewhere on the board
ADF1_LD: U2.25 (LD); also elsewhere on the board
ADF1_LE: U2.3 (LE); also elsewhere on the board
ADF_CLK: U2.1 (CLK); also elsewhere on the board
ADF_MOSI: U2.2 (DATA); also elsewhere on the board
GND: C1.1, C2.1, C3.1, C4.1, C5.1, C6.2, C7.2, C8.1, C9.1, C10.1, C11.1, C33.1, C44.1, C46.2, C47.2, C48.1, C49.1, C50.1, C51.1, C54.1, C56.1, C69.1, R1.2, R34.2, SCK1.G@1 (GND), SCK1.G@2 (GND), SCK1.G@3 (GND), SCK1.G@4 (GND), U2.8 (CPGND), U2.9 (AGND), U2.11 (AGNDVCO), U2.18 (AGNDVCO), U2.21 (AGNDVCO), U2.27 (DGND), U2.31 (SDGND), U2.PAD@1_1 (GND), U2.PAD@1_2 (GND), U2.PAD@1_3 (GND), U2.PAD@2_1 (GND), U2.PAD@2_2 (GND), U2.PAD@2_3 (GND), U2.PAD@3_1 (GND), U2.PAD@3_2 (GND), U2.PAD@3_3 (GND); also elsewhere on the board
LO1_MULT_STATUS: U2.30 (MUXOUT)
unnamed: C10.2, C11.2, U2.19 (TEMP)
unnamed: C33.2, C44.2, U2.23 (VCOM)
unnamed: C46.1, C47.1, U2.24 (VREF)
unnamed: C4.2, C5.2, L32.2, U2.6 (VP)
unnamed: C2.2, C3.2, L30.2, U2.32 (SDVDD)
unnamed: R1.1, U2.22 (RSET)
unnamed: R38.1, U2.12 (RFOUTA+)
unnamed: C53.1, R39.1, U2.13 (RFOUTA-)
unnamed: C54.2, C55.1, R35.2, U2.7 (CPOUT)
unnamed: C56.2, R35.1, U2.20 (VTUNE)
unnamed: C55.2, R34.1
unnamed: C6.1, C7.1, L31.1, U2.28 (DVDD)
unnamed: C8.2, C9.2, L27.1, U2.16 (VVCO), U2.17 (VVCO)
unnamed: C53.2, SCK1.1

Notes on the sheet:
Loop BW: 30.0kHz
Phase Margin: 45.0deg
R2: 681
CP: 2.50mA
Rset: 5.10k

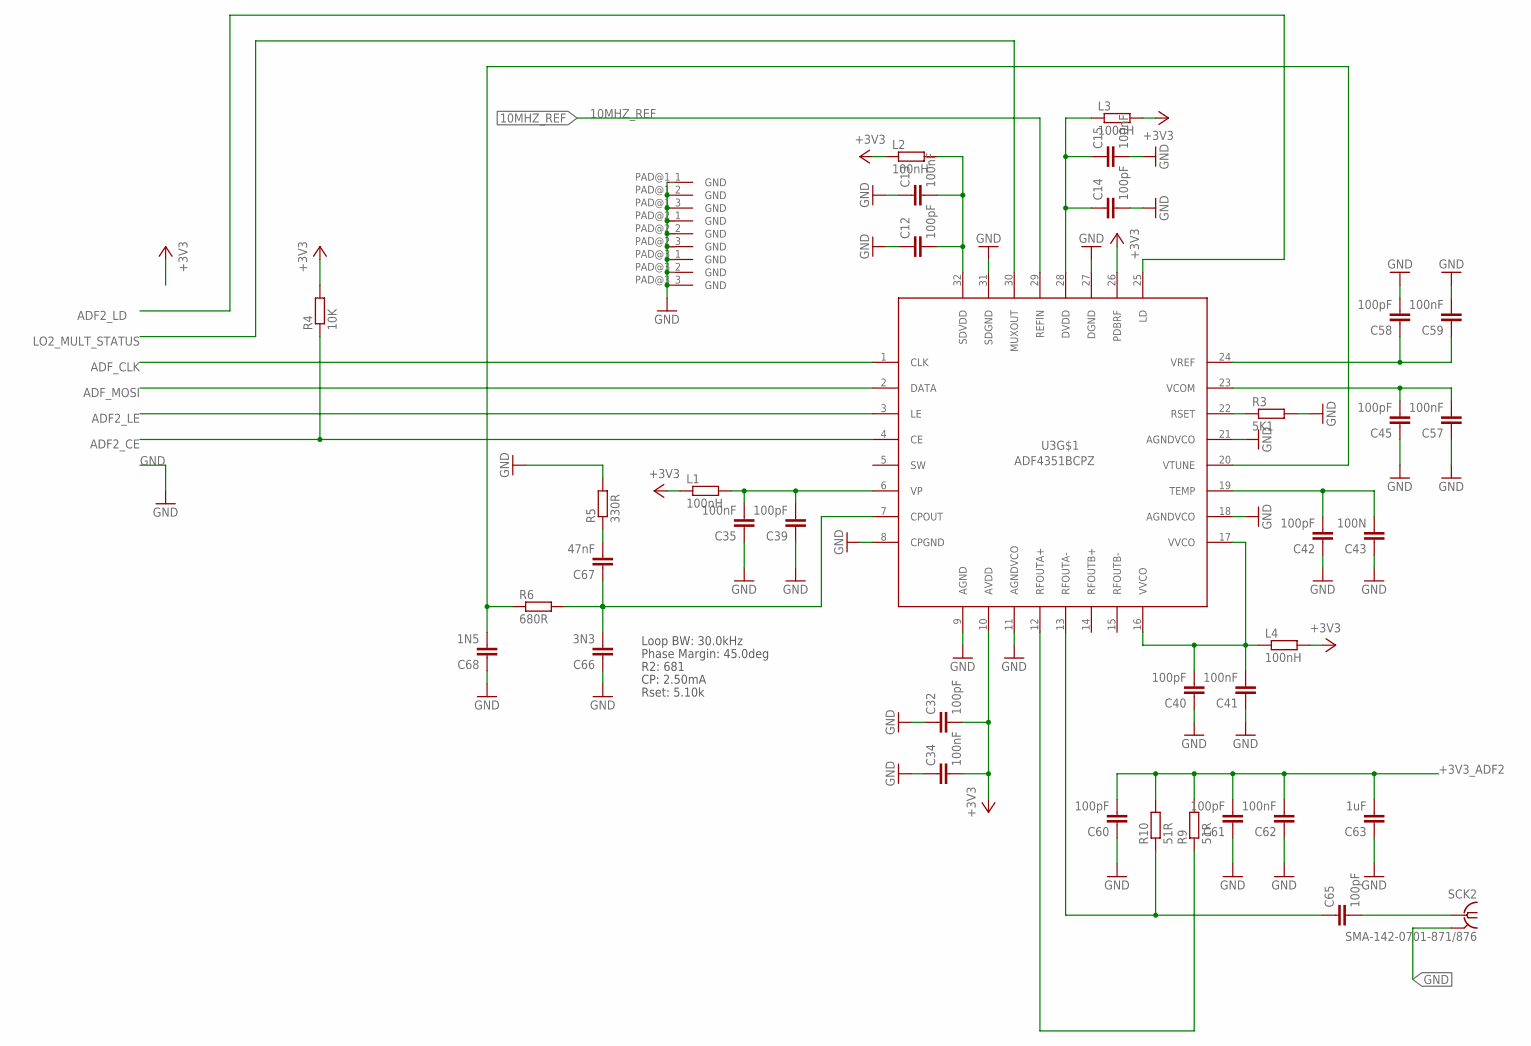
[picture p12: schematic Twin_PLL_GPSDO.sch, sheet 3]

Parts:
C12, C14, C32, C39, C40, C42, C45, C58, C60, C61, C65: 100pF; C0603
C13, C15, C34, C35, C41, C57, C59, C62: 100nF; C0603
C43: 100N; C0603
C63: 1uF; C0603
C66: 3N3; C0603
C67: 47nF; C0603
C68: 1N5; C0603
L1, L2, L3, L4: 100nH; R0603
R3: 5K1; R0603
R4: 10K; R0603
R5: 330R; R0603
R6: 680R; R0603
R9, R10: 51R; R0603
SCK2: SMA-142-0701-871/876; J502-ND-142-0701-871/876; MPN 142-0701-871
U3: ADF4351BCPZ; QFN50P500X500X100-33V2N

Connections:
10MHZ_REF: U3.29 (REFIN); also elsewhere on the board
+3V3_ADF2: C32.2, C34.2, C60.2, C61.2, C62.2, C63.2, L1.1, L2.1, L3.2, L4.2, R4.2, R9.2, R10.2, U3.10 (AVDD), U3.26 (PDBRF); also elsewhere on the board
ADF2_CE: R4.1, U3.4 (CE); also elsewhere on the board
ADF2_LD: U3.25 (LD); also elsewhere on the board
ADF2_LE: U3.3 (LE); also elsewhere on the board
ADF_CLK: U3.1 (CLK); also elsewhere on the board
ADF_MOSI: U3.2 (DATA); also elsewhere on the board
GND: C12.1, C13.1, C14.2, C15.2, C32.1, C34.1, C35.1, C39.1, C40.1, C41.1, C42.1, C43.1, C45.1, C57.1, C58.2, C59.2, C60.1, C61.1, C62.1, C63.1, C66.1, C68.1, R3.2, R5.2, SCK2.G@1 (GND), SCK2.G@2 (GND), SCK2.G@3 (GND), SCK2.G@4 (GND), U3.8 (CPGND), U3.9 (AGND), U3.11 (AGNDVCO), U3.18 (AGNDVCO), U3.21 (AGNDVCO), U3.27 (DGND), U3.31 (SDGND), U3.PAD@1_1 (GND), U3.PAD@1_2 (GND), U3.PAD@1_3 (GND), U3.PAD@2_1 (GND), U3.PAD@2_2 (GND), U3.PAD@2_3 (GND), U3.PAD@3_1 (GND), U3.PAD@3_2 (GND), U3.PAD@3_3 (GND); also elsewhere on the board
LO2_MULT_STATUS: U3.30 (MUXOUT)
unnamed: C42.2, C43.2, U3.19 (TEMP)
unnamed: C45.2, C57.2, U3.23 (VCOM)
unnamed: C58.1, C59.1, U3.24 (VREF)
unnamed: R3.1, U3.22 (RSET)
unnamed: R9.1, U3.12 (RFOUTA+)
unnamed: C65.1, R10.1, U3.13 (RFOUTA-)
unnamed: C66.2, C67.1, R6.2, U3.7 (CPOUT)
unnamed: C68.2, R6.1, U3.20 (VTUNE)
unnamed: C67.2, R5.1
unnamed: C35.2, C39.2, L1.2, U3.6 (VP)
unnamed: C12.2, C13.2, L2.2, U3.32 (SDVDD)
unnamed: C14.1, C15.1, L3.1, U3.28 (DVDD)
unnamed: C40.2, C41.2, L4.1, U3.16 (VVCO), U3.17 (VVCO)
OUTPUT: C65.2, SCK2.1

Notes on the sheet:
Loop BW: 30.0kHz
Phase Margin: 45.0deg
R2: 681
CP: 2.50mA
Rset: 5.10k

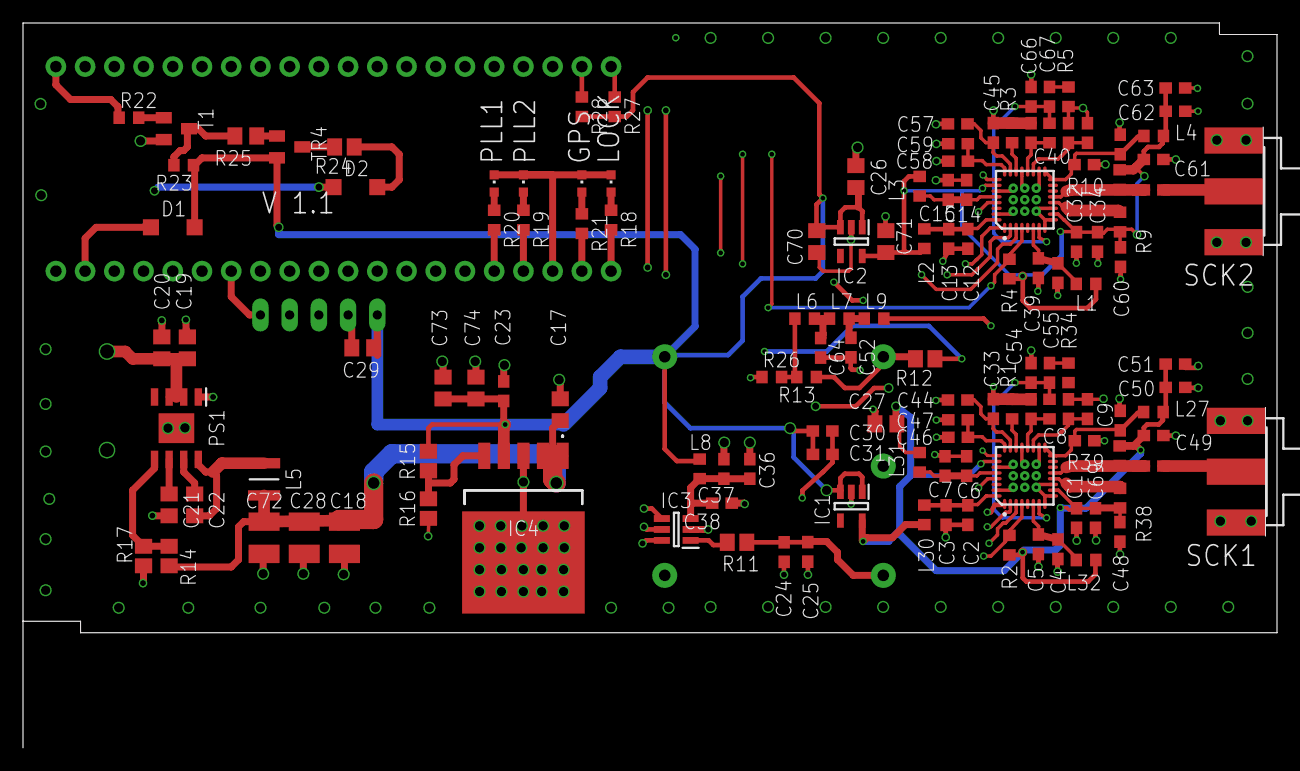
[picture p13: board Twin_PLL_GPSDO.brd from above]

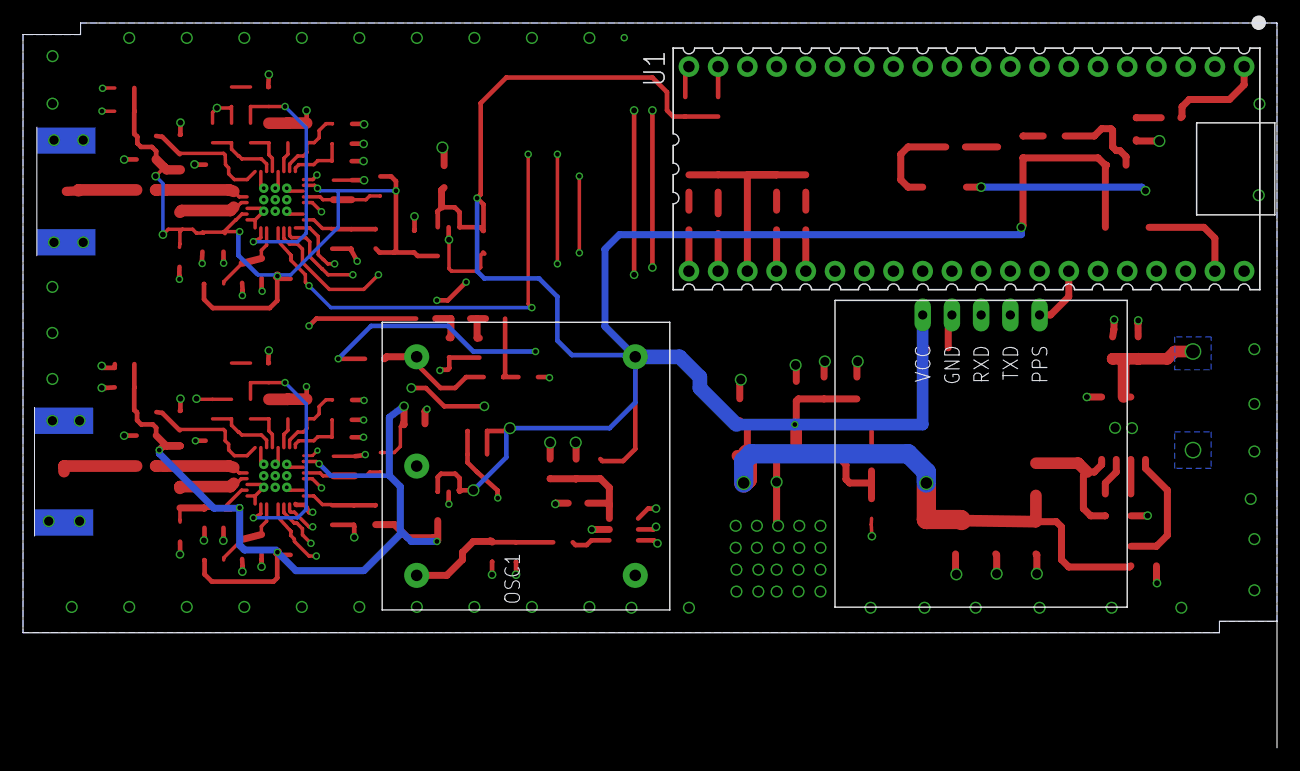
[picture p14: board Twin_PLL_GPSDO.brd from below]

Board: 4 copper layers, 109.0 x 53.0 mm, 136 parts (3 on the bottom side), 76 nets.

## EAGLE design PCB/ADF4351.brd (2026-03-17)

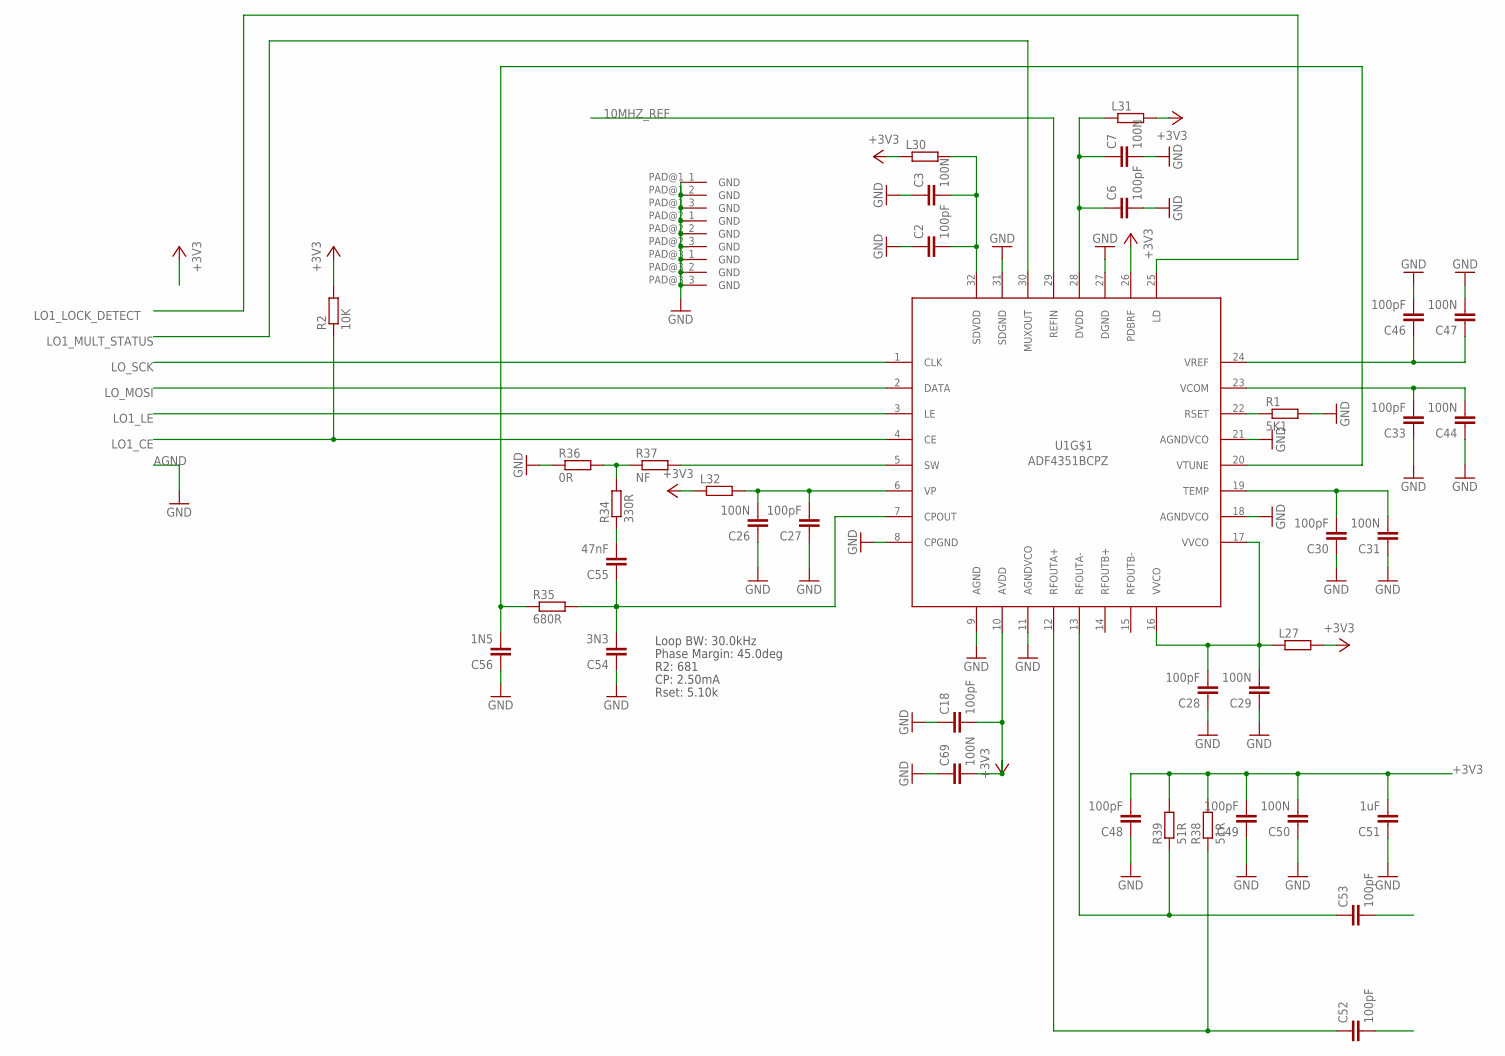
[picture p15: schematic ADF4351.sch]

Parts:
C2, C6, C18, C27, C28, C30, C33, C46, C48, C49, C52, C53: 100pF; C0603
C3, C7, C26, C29, C31, C44, C47, C50, C69: 100N; C0603
C51: 1uF; C0603
C54: 3N3; C0603
C55: 47nF; C0603
C56: 1N5; C0603
L27, L30, L31, L32: R-EU_R0603; R0603
R1: 5K1; R0603
R2: 10K; R0603
R34: 330R; R0603
R35: 680R; R0603
R36: 0R; R0603
R37: NF; R0603
R38, R39: 51R; R0603
U1: ADF4351BCPZ; QFN50P500X500X100-33V2N

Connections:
10MHZ_REF: U1.29 (REFIN)
+3V3: C18.2, C48.2, C49.2, C50.2, C51.2, C69.2, L27.2, L30.1, L31.2, L32.1, R2.2, R38.2, R39.2, U1.10 (AVDD), U1.26 (PDBRF)
AGND: C2.1, C3.1, C6.2, C7.2, C18.1, C26.1, C27.1, C28.1, C29.1, C30.1, C31.1, C33.1, C44.1, C46.2, C47.2, C48.1, C49.1, C50.1, C51.1, C54.1, C56.1, C69.1, R1.2, R36.1, U1.8 (CPGND), U1.9 (AGND), U1.11 (AGNDVCO), U1.18 (AGNDVCO), U1.21 (AGNDVCO), U1.27 (DGND), U1.31 (SDGND), U1.PAD@1_1 (GND), U1.PAD@1_2 (GND), U1.PAD@1_3 (GND), U1.PAD@2_1 (GND), U1.PAD@2_2 (GND), U1.PAD@2_3 (GND), U1.PAD@3_1 (GND), U1.PAD@3_2 (GND), U1.PAD@3_3 (GND)
LO1_CE: R2.1, U1.4 (CE)
LO1_LE: U1.3 (LE)
LO1_LOCK_DETECT: U1.25 (LD)
LO1_MULT_STATUS: U1.30 (MUXOUT)
LO_MOSI: U1.2 (DATA)
LO_SCK: U1.1 (CLK)
unnamed: C30.2, C31.2, U1.19 (TEMP)
unnamed: C33.2, C44.2, U1.23 (VCOM)
unnamed: C46.1, C47.1, U1.24 (VREF)
unnamed: C26.2, C27.2, L32.2, U1.6 (VP)
unnamed: C2.2, C3.2, L30.2, U1.32 (SDVDD)
unnamed: R1.1, U1.22 (RSET)
unnamed: C52.1, R38.1, U1.12 (RFOUTA+)
unnamed: C53.1, R39.1, U1.13 (RFOUTA-)
unnamed: C54.2, C55.1, R35.2, U1.7 (CPOUT)
unnamed: C56.2, R35.1, U1.20 (VTUNE)
unnamed: C55.2, R34.1
unnamed: R34.2, R36.2, R37.1
unnamed: R37.2, U1.5 (SW)
unnamed: C6.1, C7.1, L31.1, U1.28 (DVDD)
unnamed: C28.2, C29.2, L27.1, U1.16 (VVCO), U1.17 (VVCO)

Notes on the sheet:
Loop BW: 30.0kHz
Phase Margin: 45.0deg
R2: 681
CP: 2.50mA
Rset: 5.10k

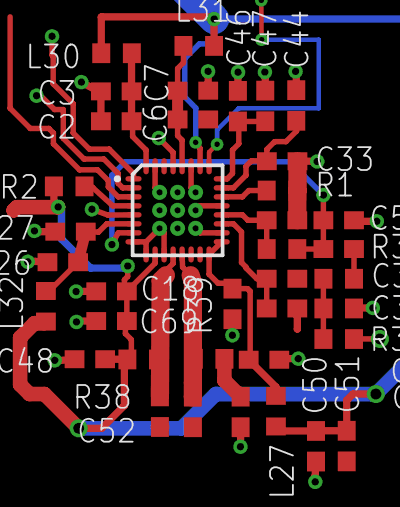
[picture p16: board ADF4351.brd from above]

Board: 4 copper layers, 38 parts (0 on the bottom side), 18 nets.

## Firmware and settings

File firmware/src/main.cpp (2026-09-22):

#include <Arduino.h>
#include <Wire.h>
#include "hardware/clocks.h"
#include "config.h"
#include "adf4351.h"
#include "mcp4725.h"
#include "gps.h"
#include "discipliner.h"
#include "status.h"
#include "pio_timing.h"
#include <EEPROM.h>
#include <LittleFS.h>
#include <ArduinoJson.h>
#include <math.h>
#include "hardware/gpio.h"
#include "hardware/pwm.h"
#include "pico/multicore.h"

// Firmware version
#ifndef FW_VERSION_STRING
#define FW_VERSION_STRING "dev"
#endif
static const char* FW_VERSION = FW_VERSION_STRING;

// Helper: emit a compact JSON response to Serial with an optional newline
static void sendJsonMessage(const char* status, const char* msg = nullptr) {
    StaticJsonDocument<192> d;
    d["status"] = status;
    if (msg) d["msg"] = msg;
    serializeJson(d, Serial);
    Serial.println();
}

static void sendJsonKV(const char* status, const char* key, int value) {
    StaticJsonDocument<192> d;
    d["status"] = status;
    d[key] = value;
    serializeJson(d, Serial);
    Serial.println();
}

static void sendTrace(const char* cmd, const char* step) {
#if ADF_TRACE_ENABLED
    StaticJsonDocument<192> d;
    d["status"] = "debug";
    d["event"] = "trace";
    d["cmd"] = cmd;
    d["step"] = step;
    serializeJson(d, Serial);
    Serial.println();
#else
    (void)cmd;
    (void)step;
#endif
}

// Mutable ADF register arrays (initialised from config defaults)
static uint32_t adf1_regs[6];
static uint32_t adf2_regs[6];
static bool adfEepromCommitPending = false;
static uint32_t adfEepromPendingMask = 0;
static uint32_t adfEepromCommitDueMs = 0;
static bool adfFsReady = false;
static bool adf1PersistDirty = false;
static bool adf2PersistDirty = false;
static uint32_t g_discAverageSecs = DISC_AVERAGE_SECS;
static bool g_adf1Enabled = (ADF1_ENABLED_DEFAULT != 0);
static bool g_adf2Enabled = (ADF2_ENABLED_DEFAULT != 0);

// ── EFC calibration state machine ─────────────────────────────────────────
enum class EFCCalState { IDLE, SETTLE_LOW, READ_LOW, SETTLE_HIGH, READ_HIGH };
static EFCCalState  g_efcCalState   = EFCCalState::IDLE;
static uint32_t     g_efcCalTimer   = 0;
static int32_t      g_efcCalFreqLow = 0;   // ppb at DAC_MIN
static int32_t      g_efcCalFreqHigh= 0;   // ppb at DAC_MAX
static const uint32_t EFC_CAL_SETTLE_MS = 15000;
static uint32_t     g_efcCalSettleMs  = EFC_CAL_SETTLE_MS;  // runtime settle time

// Forward declarations for global instances (defined later in this file)
extern Discipliner disc;
extern StatusManager status;

struct DiscCtrlBlob {
    uint32_t magic;
    uint32_t version;
    uint32_t avgWindowSecs;
    float pGain;
    float iGain;
    uint32_t warmupSecs;
    uint8_t adf1Enabled;    // v6
    uint8_t adf2Enabled;    // v6
    uint8_t _pad[2];
};

struct ADFRegsBlob {
    uint32_t magic;
    uint32_t version;
    uint32_t regs[6];
};

static const char* adfPersistPath(uint32_t eepromAddr) {
    return (eepromAddr == ADF1_EEPROM_ADDR) ? "/adf1_regs.bin" : "/adf2_regs.bin";
}

static uint32_t adfPersistDirtyMask() {
    return (adf1PersistDirty ? 0x1u : 0u) | (adf2PersistDirty ? 0x2u : 0u);
}

static void scheduleADFEEPROMCommit() {
    adfEepromCommitPending = true;
    adfEepromPendingMask = adfPersistDirtyMask();
    adfEepromCommitDueMs = millis() + (uint32_t)ADF_EEPROM_COMMIT_DELAY_MS;
}

static void stageADFRegsPersist(uint32_t eepromAddr) {
    if (eepromAddr == ADF1_EEPROM_ADDR) adf1PersistDirty = true;
    if (eepromAddr == ADF2_EEPROM_ADDR) adf2PersistDirty = true;
}

static void writeADFRegsEEPROMBlock(const uint32_t regs[6], uint32_t eepromAddr) {
    uint32_t magic = ADF_REGS_MAGIC;
    uint32_t version = ADF_REGS_VERSION;
    EEPROM.put(eepromAddr, magic);
    EEPROM.put(eepromAddr + sizeof(magic), version);
    for (int i = 0; i < 6; ++i) {
        EEPROM.put(eepromAddr + sizeof(magic) + sizeof(version) + i * sizeof(uint32_t), regs[i]);
    }
}

static bool commitStagedADFRegsToEEPROM() {
    const uint32_t mask = adfPersistDirtyMask();
    if (mask == 0) {
        return true;
    }

    if (adf1PersistDirty) writeADFRegsEEPROMBlock(adf1_regs, ADF1_EEPROM_ADDR);
    if (adf2PersistDirty) writeADFRegsEEPROMBlock(adf2_regs, ADF2_EEPROM_ADDR);

    sendTrace("adf_persist", "commit_pre");
    bool committed = false;
#if ADF_EEPROM_USE_LOCKOUT
    sendTrace("adf_persist", "lockout_enter");
    multicore_lockout_start_blocking();
    committed = EEPROM.commit();
    multicore_lockout_end_blocking();
    sendTrace("adf_persist", "lockout_exit");
#else
    // Gate PIO interrupt sources globally during commit.
    sendTrace("adf_persist", "pio_irq_src_off");
    pio_set_irq0_source_enabled(pio0, pis_interrupt0, false);
    pio_set_irq1_source_enabled(pio0, pis_interrupt1, false);

    sendTrace("adf_persist", "commit_call");
    committed = EEPROM.commit();
    sendTrace("adf_persist", "commit_return");

    pio_set_irq0_source_enabled(pio0, pis_interrupt0, true);
    pio_set_irq1_source_enabled(pio0, pis_interrupt1, true);
    sendTrace("adf_persist", "pio_irq_src_on");
#endif
    sendTrace("adf_persist", committed ? "commit_ok" : "commit_fail");

    if (committed) {
        StaticJsonDocument<192> dj;
        dj["status"] = "info";
        dj["event"] = "eeprom_write_success";
        dj["component"] = "adf_persist";
        dj["mask"] = mask;
        serializeJson(dj, Serial);
        Serial.println();

        adf1PersistDirty = false;
        adf2PersistDirty = false;
    }
    return committed;
}

static bool commitEEPROMNow() {
    bool committed = false;
#if ADF_EEPROM_USE_LOCKOUT
    multicore_lockout_start_blocking();
    committed = EEPROM.commit();
    multicore_lockout_end_blocking();
#else
    pio_set_irq0_source_enabled(pio0, pis_interrupt0, false);
    pio_set_irq1_source_enabled(pio0, pis_interrupt1, false);
    committed = EEPROM.commit();
    pio_set_irq0_source_enabled(pio0, pis_interrupt0, true);
    pio_set_irq1_source_enabled(pio0, pis_interrupt1, true);
#endif
    return committed;
}

static bool saveDiscCtrlSettings(bool emitJson = true) {
    DiscCtrlBlob blob{};
    blob.magic = DISC_CTRL_MAGIC;
    blob.version = DISC_CTRL_VERSION;
    blob.avgWindowSecs = g_discAverageSecs;
    blob.pGain = disc.pGain();
    blob.iGain = disc.iGain();
    blob.warmupSecs = disc.warmupSecs();
    blob.adf1Enabled = g_adf1Enabled ? 1 : 0;
    blob.adf2Enabled = g_adf2Enabled ? 1 : 0;

    EEPROM.put(DISC_CTRL_EEPROM_ADDR, blob);
    bool committed = commitEEPROMNow();

    if (emitJson) {
        StaticJsonDocument<256> dj;
        dj["status"] = committed ? "info" : "error";
        dj["event"] = "saved_disc_ctrl";
        dj["committed"] = committed;
        dj["avg_window_s"] = blob.avgWindowSecs;
        dj["p_gain"] = blob.pGain;
        dj["i_gain"] = blob.iGain;
        dj["warmup_s"] = blob.warmupSecs;
        dj["adf1_enabled"] = g_adf1Enabled;
        dj["adf2_enabled"] = g_adf2Enabled;
        serializeJson(dj, Serial);
        Serial.println();
    }
    return committed;
}

static bool loadDiscCtrlSettings(bool emitJson = true) {
    DiscCtrlBlob blob{};
    EEPROM.get(DISC_CTRL_EEPROM_ADDR, blob);

    bool ok = (blob.magic == DISC_CTRL_MAGIC) && (blob.version == DISC_CTRL_VERSION);
    ok = ok && (blob.avgWindowSecs >= DISC_AVERAGE_SECS_MIN) && (blob.avgWindowSecs <= DISC_AVERAGE_SECS_USER_MAX);
    ok = ok && disc.setLoopGains(blob.pGain, blob.iGain);
    ok = ok && disc.setWarmupSecs(blob.warmupSecs);

    if (ok) {
        g_discAverageSecs = blob.avgWindowSecs;
        g_adf1Enabled = (blob.adf1Enabled != 0);
        g_adf2Enabled = (blob.adf2Enabled != 0);
    } else {
        g_discAverageSecs = DISC_AVERAGE_SECS;
        disc.setLoopGains(DISC_P_GAIN, DISC_I_GAIN);
        disc.setWarmupSecs(DISC_WARMUP_SECS);
        g_adf1Enabled = (ADF1_ENABLED_DEFAULT != 0);
        g_adf2Enabled = (ADF2_ENABLED_DEFAULT != 0);
    }
    status.setDiscAvgWindowSecs(g_discAverageSecs);
    status.setAdf1Enabled(g_adf1Enabled);
    status.setAdf2Enabled(g_adf2Enabled);

    if (emitJson) {
        StaticJsonDocument<256> dj;
        dj["status"] = ok ? "info" : "warning";
        dj["event"] = ok ? "loaded_disc_ctrl" : "using_default_disc_ctrl";
        dj["avg_window_s"] = g_discAverageSecs;
        dj["p_gain"] = disc.pGain();
        dj["i_gain"] = disc.iGain();
        dj["warmup_s"] = disc.warmupSecs();
        dj["adf1_enabled"] = g_adf1Enabled;
        dj["adf2_enabled"] = g_adf2Enabled;
        serializeJson(dj, Serial);
        Serial.println();
    }
    return ok;
}
// Presence/attempt tracking
enum class PeripheralStatus { PS_UNKNOWN=0, PS_OK=1, PS_ABSENT=2 };
static PeripheralStatus haveDAC = PeripheralStatus::PS_UNKNOWN;
static PeripheralStatus haveADF1 = PeripheralStatus::PS_UNKNOWN;
static PeripheralStatus haveADF2 = PeripheralStatus::PS_UNKNOWN;
static int adf1_attempts = 0;
static int adf2_attempts = 0;
static const int MAX_ADF_ATTEMPTS = 3;

// forward declarations for CLI helper usage (instances defined below)
extern ADF4351 adf1;
extern ADF4351 adf2;
extern Discipliner disc;

// Helper: load regs from EEPROM if magic/version match, otherwise use defaults
static void loadADFRegs(uint32_t regs[6], const uint32_t defaults[6], uint32_t eepromAddr) {
    if (adfFsReady) {
        const char* path = adfPersistPath(eepromAddr);
        File f = LittleFS.open(path, "r");
        if (f) {
            ADFRegsBlob blob{};
            size_t n = f.read((uint8_t*)&blob, sizeof(blob));
            f.close();
            if (n == sizeof(blob) && blob.magic == ADF_REGS_MAGIC && blob.version == ADF_REGS_VERSION) {
                for (int i = 0; i < 6; ++i) regs[i] = blob.regs[i];
                StaticJsonDocument<192> dj;
                dj["status"] = "info";
                dj["event"] = "loaded_adf_regs";
                dj["path"] = path;
                serializeJson(dj, Serial);
                Serial.println();
                return;
            }
        }
    }

    // Fallback: read persisted ADF registers from EEPROM block format.
    uint32_t magic = 0;
    uint32_t version = 0;
    EEPROM.get((int)eepromAddr, magic);
    EEPROM.get((int)(eepromAddr + sizeof(magic)), version);
    if (magic == ADF_REGS_MAGIC && version == ADF_REGS_VERSION) {
        for (int i = 0; i < 6; ++i) {
            uint32_t v = 0;
            EEPROM.get((int)(eepromAddr + sizeof(magic) + sizeof(version) + i * sizeof(uint32_t)), v);
            regs[i] = v;
        }
        StaticJsonDocument<192> dj;
        dj["status"] = "info";
        dj["event"] = "loaded_adf_regs";
        dj["eeprom_addr"] = (unsigned)eepromAddr;
        serializeJson(dj, Serial);
        Serial.println();
        return;
    }

    for (int i = 0; i < 6; ++i) regs[i] = defaults[i];
    {
        StaticJsonDocument<192> dj;
        dj["status"] = "info";
        dj["event"] = "using_default_adf_regs";
        dj["eeprom_addr"] = (unsigned)eepromAddr;
        serializeJson(dj, Serial);
        Serial.println();
    }
}

static bool saveADFRegs(uint32_t regs[6], uint32_t eepromAddr) {
#if !ADF_PERSIST_EEPROM
    (void)regs;
    stageADFRegsPersist(eepromAddr);
#if ADF_AUTO_COMMIT_STAGED
    scheduleADFEEPROMCommit();
#endif
    {
        StaticJsonDocument<192> dj;
        dj["status"] = "info";
        dj["event"] = "saved_adf_regs";
        dj["eeprom_addr"] = (unsigned)eepromAddr;
        dj["staged"] = true;
        dj["pending_mask"] = adfPersistDirtyMask();
        dj["skipped"] = true;
        dj["committed"] = false;
#if ADF_AUTO_COMMIT_STAGED
        dj["auto_commit"] = true;
#else
        dj["auto_commit"] = false;
#endif
        serializeJson(dj, Serial);
        Serial.println();
    }
    return true;
#else
    if (!adfFsReady) {
        sendJsonMessage("error", "adf_persist_fs_not_ready");
        return false;
    }

    const char* path = adfPersistPath(eepromAddr);
    {
        StaticJsonDocument<160> dj;
        dj["status"] = "debug";
        dj["event"] = "adf_persist_write_start";
        dj["path"] = path;
        serializeJson(dj, Serial);
        Serial.println();
    }

    ADFRegsBlob blob{};
    blob.magic = ADF_REGS_MAGIC;
    blob.version = ADF_REGS_VERSION;
    for (int i = 0; i < 6; ++i) blob.regs[i] = regs[i];

    File f = LittleFS.open(path, "w");
    if (!f) {
        sendJsonMessage("error", "adf_persist_open_failed");
        return false;
    }
    size_t n = f.write((const uint8_t*)&blob, sizeof(blob));
    f.flush();
    f.close();
    bool committed = (n == sizeof(blob));

    {
        StaticJsonDocument<192> dj;
        dj["status"] = committed ? "info" : "error";
        dj["event"] = "saved_adf_regs";
        dj["path"] = path;
        dj["committed"] = committed;
        serializeJson(dj, Serial);
        Serial.println();
    }
    return committed;
#endif
}
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
void loop() {
    // CLI input first (FIFO buffered, non-blocking) so command handling stays
    // responsive even if other subsystems are degraded.
    pollSerialIntoCLIQueue();
    String nextCmd;
    if (dequeueCLICommand(nextCmd)) {
        handleCLI(nextCmd);
    }

    // Handle staged EEPROM commit outside command handlers.
    serviceADFEEPROMCommit();

    // Parse incoming GPS NMEA sentences
    gps.update();

    // Collect PIO timing result (Core1 populates this via IRQ)
    TimingResult tr = timing.getResult();
    const GPSState& gs = gps.state();

    bool gpsGood = gs.hasFix && gs.ppsValid;

    // Rolling ring buffer of per-second raw count errors (integer Hz).
    // By accumulating exact integer deviations from nominal and only
    // converting to ppb at the very end, we eliminate all intermediate
    // floating-point quantisation — one extra count in 64 s = 0.156 ppb.
    static int32_t  countErrRing[DISC_AVERAGE_SECS_MAX];
    static int64_t  countErrSum      = 0;   // running sum of ring contents
    static uint32_t countErrRingIdx  = 0;
    static uint32_t countErrRingCount = 0;

    // EFC calibration state machine — suspends normal discipliner while running.
    if (g_efcCalState != EFCCalState::IDLE) {
        if (tr.freqValid) status.setMeasuredOCXO(tr.measuredFreq_Hz, tr.freqError_ppb);
        uint32_t elapsed = millis() - g_efcCalTimer;
        switch (g_efcCalState) {
            case EFCCalState::SETTLE_LOW:
                if (elapsed >= g_efcCalSettleMs) {
                    g_efcCalState = EFCCalState::READ_LOW;
                    g_efcCalTimer = millis();
                }
                break;
            case EFCCalState::READ_LOW:
                if (tr.freqValid) {
                    g_efcCalFreqLow = tr.freqError_ppb;
                    disc.setDACValue(DAC_MAX);
                    g_efcCalTimer = millis();
                    g_efcCalState = EFCCalState::SETTLE_HIGH;
                    StaticJsonDocument<128> dj2;
                    dj2["event"] = "efc_cal";
                    dj2["step"] = "low_read";
                    dj2["dac"] = DAC_MIN;
                    dj2["freq_error_ppb"] = g_efcCalFreqLow;
                    serializeJson(dj2, Serial); Serial.println();
                }
                break;
            case EFCCalState::SETTLE_HIGH:
                if (elapsed >= g_efcCalSettleMs) {
                    g_efcCalState = EFCCalState::READ_HIGH;
                    g_efcCalTimer = millis();
                }
                break;
            case EFCCalState::READ_HIGH:
                if (tr.freqValid) {
                    g_efcCalFreqHigh = tr.freqError_ppb;
                    int32_t swing_ppb = g_efcCalFreqHigh - g_efcCalFreqLow;
                    int32_t dac_span  = DAC_MAX - DAC_MIN;
                    float slope = (dac_span > 0) ? (float)swing_ppb / (float)dac_span : 0.0f;
                    StaticJsonDocument<256> dj3;
                    dj3["event"] = "efc_cal";
                    dj3["step"] = "done";
                    dj3["dac_min"] = DAC_MIN;
                    dj3["dac_max"] = DAC_MAX;
                    dj3["freq_at_min_ppb"] = g_efcCalFreqLow;
                    dj3["freq_at_max_ppb"] = g_efcCalFreqHigh;
                    dj3["swing_ppb"] = swing_ppb;
                    dj3["slope_ppb_per_dac"] = slope;
                    serializeJson(dj3, Serial); Serial.println();
                    // Restore DAC to centre and re-enter discipliner
                    disc.setDACValue(DAC_CENTRE);
                    disc.resetIntegral();
                    disc.setCalActive(false);
                    countErrRingIdx = 0;
                    countErrRingCount = 0;
                    countErrSum = 0;
                    g_efcCalState = EFCCalState::IDLE;
                }
                break;
            default: break;
        }
        // Skip normal discipliner loop while calibrating
        goto skip_discipliner;
    }

    // Advance warmup/state-machine every second regardless of freq measurement.
    // Warmup depends on GPS validity, not on having a frequency reading.
    disc.tickWarmup(gpsGood);

    if (tr.freqValid) {
        status.setMeasuredOCXO(tr.measuredFreq_Hz, tr.freqError_ppb);

        // Detect ACQUIRING → LOCKED transition and zero the count
        // accumulator so the locked-mode window starts clean, without
        // stale pull-in residuals from the acquiring phase.
        static DiscState prevDiscState = DiscState::WARMUP;
        DiscState curDiscState = disc.state();
        if (curDiscState == DiscState::LOCKED && prevDiscState != DiscState::LOCKED) {
            memset(countErrRing, 0, sizeof(countErrRing));
            countErrRingIdx   = 0;
            countErrRingCount = 0;
            countErrSum       = 0;
        }
        prevDiscState = curDiscState;

        // Feed DAC snapshot into lock detection ring buffer every second
        disc.feedLockSample();

        // Push this second's raw count error into the ring buffer and
        // maintain the running sum so we never need to re-scan.
        int32_t thisCountErr = tr.freqError_Hz;  // exact integer

        if (countErrRingCount >= DISC_AVERAGE_SECS_MAX) {
            // Ring full — subtract the sample we're about to overwrite
            countErrSum -= countErrRing[countErrRingIdx];
        }
        countErrRing[countErrRingIdx] = thisCountErr;
        countErrSum += thisCountErr;
        countErrRingIdx = (countErrRingIdx + 1) % DISC_AVERAGE_SECS_MAX;
        if (countErrRingCount < DISC_AVERAGE_SECS_MAX) countErrRingCount++;

        // Acquiring: base window + full gain for fast pull-in.
        // Locked:    window * DISC_AVG_LOCKED_MULTIPLY + gain * LOCKED_RATIO.
        uint32_t effectiveAvgSecs = (disc.state() == DiscState::LOCKED)
                                    ? g_discAverageSecs * DISC_AVG_LOCKED_MULTIPLY
                                    : g_discAverageSecs;
        if (effectiveAvgSecs > DISC_AVERAGE_SECS_MAX) effectiveAvgSecs = DISC_AVERAGE_SECS_MAX;
        if (effectiveAvgSecs < 1) effectiveAvgSecs = 1;
        status.setDiscAvgWindowSecs(effectiveAvgSecs);

        // Sum the most recent effectiveAvgSecs count errors.
        // If the ring hasn't filled to effectiveAvgSecs yet, use what we have.
        uint32_t usable = (countErrRingCount < effectiveAvgSecs)
                          ? countErrRingCount : effectiveAvgSecs;
        if (usable > 0) {
            // When usable == countErrRingCount we can use the running sum
            // directly; otherwise re-sum the most recent 'usable' entries.
            int64_t windowSum;
            if (usable == countErrRingCount) {
                windowSum = countErrSum;
            } else {
                windowSum = 0;
                for (uint32_t i = 0; i < usable; i++) {
                    uint32_t idx = (countErrRingIdx + DISC_AVERAGE_SECS_MAX - 1 - i)
                                   % DISC_AVERAGE_SECS_MAX;
                    windowSum += countErrRing[idx];
                }
            }
            double avgCountErr = (double)windowSum / (double)usable;
            status.setCountErrSum(windowSum);
            disc.update(avgCountErr, gpsGood);
        }
    } else if (!gpsGood) {
        countErrRingIdx   = 0;
        countErrRingCount = 0;
        countErrSum       = 0;
        disc.update(0, false);
    }

    skip_discipliner:

    // Log OCXO frequency measurement every 10 seconds
    if (tr.freqValid) {
        static uint32_t lastFreqLog = 0;
        if (millis() - lastFreqLog >= 10000) {
            lastFreqLog = millis();
            StaticJsonDocument<256> dj;
            dj["event"] = "ocxo";
            dj["pulse_count"] = tr.freqPulseCount;
            dj["measured_hz"] = tr.measuredFreq_Hz;
            dj["freq_error_ppb"] = tr.freqError_ppb;
            dj["dac_value"] = disc.dacValue();
            switch (disc.state()) {
                case DiscState::WARMUP:    dj["disc_state"] = "WARMUP";    break;
                case DiscState::ACQUIRING: dj["disc_state"] = "ACQUIRING"; break;
                case DiscState::LOCKED:    dj["disc_state"] = "LOCKED";    break;
                case DiscState::HOLDOVER:  dj["disc_state"] = "HOLDOVER";  break;
                case DiscState::FREERUN:   dj["disc_state"] = "FREERUN";   break;
            }
            serializeJson(dj, Serial);
            Serial.println();
        }
    }

    // LEDs, alarm, periodic debug print
    status.update();

    // heartbeat removed — use presence of JSON status messages instead
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

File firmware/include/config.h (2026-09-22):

#pragma once

#include <stdint.h>

// ============================================================
// GPSDO + Dual ADF4351 Reference Source
// Hardware Configuration
// ============================================================

// --- GPS ---
#define GPS_UART        uart1
#define GPS_TX_PIN      20   // Pico TX → GPS module RX  (schematic: GPS_RX)
#define GPS_RX_PIN      21   // Pico RX ← GPS module TX  (schematic: GPS_TX)
#define GPS_1PPS_PIN    28
#define GPS_BAUD        9600

// --- 10MHz frequency counter input (from OCXO) ---
#define FREQ_COUNT_PIN  22

// --- ADF4351 shared SPI-like bus (bit-banged) ---
// GPIO8 is not a valid hardware SPI MOSI/TX pin on this core (SPI0 or SPI1),
// so these pins are clocked manually in adf4351.cpp rather than via the
// Arduino SPI peripheral. Fixed by hardware wiring, not configurable.
#define ADF_SCK_PIN     6    // shared SCK
#define ADF_MOSI_PIN    8    // shared MOSI / TX

// --- ADF4351 #1 (104 MHz) ---
#define ADF1_LE_PIN     4    // latch enable
#define ADF1_CE_PIN     12
#define ADF1_LD_PIN     10   // lock detect

// Default PLL1 enable state (runtime-configurable via pll_ctrl command).
#define ADF1_ENABLED_DEFAULT  1

// --- ADF4351 #2 (116 MHz) ---
#define ADF2_LE_PIN     9    // latch enable
#define ADF2_CE_PIN     13
#define ADF2_LD_PIN     11   // lock detect

// Default PLL2 enable state (runtime-configurable via pll_ctrl command).
#define ADF2_ENABLED_DEFAULT  1

// --- I2C for MCP4725 DAC (OCXO EFC) ---
// GPIO14/15 are only valid I2C1 pins (Wire1), not I2C0 (Wire) — code must
// use Wire1.setSDA()/setSCL() to match, not the default Wire instance.
#define I2C_SDA_PIN     14
#define I2C_SCL_PIN     15
#define MCP4725_ADDR    0x60  // A0 tied low

// --- PWM DAC option (bypass MCP4725 for quick bench test) ---
// Set USE_PWM_DAC to 1 to use RP2040/RP2350 PWM output as an EFC DAC.
// Requires an external RC low-pass filter on PWM_DAC_PIN to smooth to DC.
// Uses 12-bit analogWrite so range and limits match MCP4725 (0-4095).
// Set to 0 to use the I2C MCP4725 DAC (normal operation).
#define USE_PWM_DAC     0
#define PWM_DAC_PIN     25

// --- Status LEDs ---
#define LED_GPS_DISC    16   // GPS discipline active
#define LED_GPS_LOCK    17   // GPS lock
#define LED_ADF1_LOCK   18
#define LED_ADF2_LOCK   19
#define LED_ALARM       27

// Additional spare LEDs (optional, not on schematic)
// LED that flashes at 0.5s intervals when any satellites are present
#define LED_SATS_BLINK  23
// LED that indicates a usable fix (satellites in use >= 4)
#define LED_SATS_USED   24

// --- Alarm output (open collector via BC847 + R22) ---
#define ALARM_PIN       0

// --- Debug UART ---
#define DEBUG_TX_PIN    3

// ============================================================
// ADF4351 Register Values
// Calculated for:
//   OCXO ref = 10MHz, R=5, PFD=2MHz
//   Integer-N mode, output divider /32
//   Output power = 0dBm (+3dBm register setting,
//   external attenuator to taste)
//
// IMPORTANT: Verify these with ADIsimPLL before use.
// Register order: R0..R5 (written R5 first, R0 last)
// ============================================================

// --- 104 MHz: VCO=3328MHz, N=1664, /32 ---
// R0: INT=1664, FRAC=0
// R1: MOD=1, PHASE=1, prescaler 8/9
// R2: low-noise mode, MUXOUT=digital lock, R=5, CP=2.50mA,
//     integer-N lock detect settings (DB8:DB7 = 11)
// R3: clock divider value = 150, mode off
// R4: feedback=fundamental, RF div=/32, band select clk div=150,
//     RF out enable, +5dBm
// R5: LD pin = digital lock detect
static const uint32_t ADF1_REGS[6] = {
    0x03400000,  // R0
    0x08008009,  // R1
    0x18014FC2,  // R2
    0x000004B3,  // R3: clk div=150
    0x00D9603C,  // R4
    0x00580005   // R5: LD=digital lock detect
};

// --- 116 MHz: VCO=3712MHz, N=1856, /32 ---
static const uint32_t ADF2_REGS[6] = {
    0x03A00000,  // R0
    0x08008009,  // R1
    0x18014FC2,  // R2
    0x000004B3,  // R3: same as above
    0x00D9603C,  // R4
    0x00580005   // R5: same as above
};

// Nominal OCXO frequency (Hz) — used for count-error arithmetic
#define OCXO_NOMINAL_HZ     10000000

// ============================================================
// GPSDO Disciplining Parameters
// ============================================================
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

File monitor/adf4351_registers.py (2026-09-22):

from __future__ import annotations

from dataclasses import dataclass
from math import ceil, gcd
from typing import List, Literal


PrescalerMode = Literal["auto", "4/5", "8/9"]
NoiseMode = Literal["low_noise", "low_spur"]


@dataclass(frozen=True)
class ADF4351Config:
    ref_hz: float = 10_000_000.0
    r_counter: int = 5
    ref_doubler: bool = False
    ref_div2: bool = False
    channel_spacing_hz: float = 1.0
    phase: int = 1
    prescaler: PrescalerMode = "auto"
    integer_n: bool = True
    charge_pump_code: int = 7
    pd_polarity_positive: bool = True
    band_select_clock_div: int = 150
    rf_output_enable: bool = True
    rf_output_power_code: int = 3
    feedback_fundamental: bool = True
    lock_detect_pin_digital: bool = True
    noise_mode: NoiseMode = "low_noise"


@dataclass(frozen=True)
class ADF4351Solution:
    target_hz: float
    actual_hz: float
    pfd_hz: float
    vco_hz: float
    output_divider: int
    int_value: int
    frac_value: int
    mod_value: int
    prescaler_89: bool
    registers_r0_to_r5: List[int]

    @property
    def registers_r5_to_r0(self) -> List[int]:
        return list(reversed(self.registers_r0_to_r5))

    @property
    def error_hz(self) -> float:
        return self.actual_hz - self.target_hz


@dataclass(frozen=True)
class ADF4351Decoded:
    int_value: int
    frac_value: int
    mod_value: int
    r_counter: int
    ref_doubler: bool
    ref_div2: bool
    rf_divider: int
    prescaler_89: bool
    pfd_hz: float
    vco_hz: float
    rf_out_hz: float
    charge_pump_code: int
    rf_output_power_code: int
    noise_mode: NoiseMode


class ADF4351RegisterCalculator:
    VCO_MIN_HZ = 2_200_000_000.0
    VCO_MAX_HZ = 4_400_000_000.0
    RF_DIVIDERS = (1, 2, 4, 8, 16, 32, 64)

    def __init__(self, config: ADF4351Config | None = None) -> None:
        self.config = config or ADF4351Config()
        self._validate_config(self.config)

    @staticmethod
    def _validate_config(config: ADF4351Config) -> None:
        if not (1 <= config.r_counter <= 1023):
            raise ValueError("r_counter must be in 1..1023")
        if config.ref_hz <= 0:
            raise ValueError("ref_hz must be > 0")
        if config.channel_spacing_hz <= 0:
            raise ValueError("channel_spacing_hz must be > 0")
        if not (1 <= config.phase <= 4095):
            raise ValueError("phase must be in 1..4095")
        if not (0 <= config.charge_pump_code <= 15):
            raise ValueError("charge_pump_code must be in 0..15")
        if not (1 <= config.band_select_clock_div <= 255):
            raise ValueError("band_select_clock_div must be in 1..255")
        if not (0 <= config.rf_output_power_code <= 3):
            raise ValueError("rf_output_power_code must be in 0..3")

    def pfd_hz(self) -> float:
        doubler = 2.0 if self.config.ref_doubler else 1.0
        div2 = 2.0 if self.config.ref_div2 else 1.0
        return (self.config.ref_hz * doubler) / (self.config.r_counter * div2)

    def solve(self, target_hz: float) -> ADF4351Solution:
        if target_hz <= 0:
            raise ValueError("target_hz must be > 0")

        output_div = self._choose_output_divider(target_hz)
        vco_hz = target_hz * output_div
        pfd = self.pfd_hz()

        n_float = vco_hz / pfd
        int_value, frac_value, mod_value = self._synthesize_n(n_float, pfd)
        prescaler_89 = self._choose_prescaler(int_value)

        self._validate_n(int_value, mod_value, prescaler_89)
        self._validate_mode_limits(pfd_hz=pfd, is_fractional=(frac_value != 0))
        self._validate_band_select_clock(pfd_hz=pfd)

        actual_vco_hz = pfd * (int_value + (frac_value / mod_value))
        actual_hz = actual_vco_hz / output_div

        regs = self._build_registers(
            int_value=int_value,
            frac_value=frac_value,
            mod_value=mod_value,
            prescaler_89=prescaler_89,
            rf_divider=output_div,
        )

        return ADF4351Solution(
            target_hz=target_hz,
            actual_hz=actual_hz,
            pfd_hz=pfd,
            vco_hz=actual_vco_hz,
            output_divider=output_div,
            int_value=int_value,
            frac_value=frac_value,
            mod_value=mod_value,
            prescaler_89=prescaler_89,
            registers_r0_to_r5=regs,
        )

    @staticmethod
    def _validate_mode_limits(pfd_hz: float, is_fractional: bool) -> None:
        if is_fractional and pfd_hz > 32_000_000.0:
            raise ValueError("Fractional-N mode requires PFD <= 32 MHz")
        if (not is_fractional) and pfd_hz > 90_000_000.0:
            raise ValueError("Integer-N mode requires PFD <= 90 MHz")

    def _validate_band_select_clock(self, pfd_hz: float) -> None:
        band_select_clk_hz = pfd_hz / self.config.band_select_clock_div
        if band_select_clk_hz > 125_000.0:
            raise ValueError(
                "Band-select clock exceeds 125 kHz in low mode; increase band_select_clock_div"
            )

    @classmethod
    def decode_registers(
        cls,
        registers_r0_to_r5: List[int],
        ref_hz: float,
    ) -> ADF4351Decoded:
        if len(registers_r0_to_r5) != 6:
            raise ValueError("registers_r0_to_r5 must have exactly 6 entries")
        if ref_hz <= 0:
            raise ValueError("ref_hz must be > 0")

        r0, r1, r2, _, r4, _ = registers_r0_to_r5

        int_value = (r0 >> 15) & 0xFFFF
        frac_value = (r0 >> 3) & 0x0FFF
        mod_value = (r1 >> 3) & 0x0FFF
        mod_value = mod_value if mod_value > 0 else 1

        prescaler_89 = bool((r1 >> 27) & 0x1)

        ref_doubler = bool((r2 >> 25) & 0x1)
        ref_div2 = bool((r2 >> 24) & 0x1)
        r_counter = (r2 >> 14) & 0x03FF
        r_counter = r_counter if r_counter > 0 else 1
        charge_pump_code = (r2 >> 9) & 0x0F

        rf_div_sel = (r4 >> 20) & 0b111
        rf_divider = 1 << rf_div_sel
        rf_output_power_code = (r4 >> 3) & 0b11

        noise_mode_bits = (r2 >> 29) & 0b11
        noise_mode: NoiseMode = "low_noise" if noise_mode_bits == 0b00 else "low_spur"
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

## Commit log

2026-03-17 v0.0.7
    added registers button for direct register entry
    added tech readmo
    [ADF4351.brd, ADF4351.sch, Twin_PLL_GPSDO.brd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]
2026-03-17 PID tuning dialogue
2026-03-29 Fix double integration: feed average count error to PI loop, I_GAIN=5.0
    - discipliner.update() now takes double avgCountError instead of int64_t sum
    - main.cpp computes (double)windowSum / usable before calling update()
    - I_GAIN bumped to 5.0 (locked eff=2.5) for ~30s convergence
    - DISC_CTRL_VERSION bumped to 5 to force fresh gains over stale EEPROM
    - Verified: converges to count_err_sum=0, DAC stable at lock point
    [config.h, main.cpp, status.cpp]
2026-03-29 Update REFERENCE_LOCKING_README for integer count accumulator architecture
    - Signal flow diagram updated: ring buffer + average count error path
    - Section 3 rewritten: integer ring buffer, running sum, avg/N to integrator
    - Gain units clarified: DAC counts per Hz-error (not ppb-based 1/N scaling)
    - Current defaults: I_GAIN=5.0, locked ratio=0.5, window 16s/64s
    - Telemetry fields updated: disc_count_err, disc_avg_count_err, count_err_sum
    - Quick reference table updated with current values
    - Zero-on-lock-entry documented
2026-03-29 Monitor: add count_err_sum and avg count error to tuning Status box
    - Tuning Status box now shows Avg count err (Hz) and Count err sum
    - Overview details label updated: 'Disc avg freq err (ppb)' -> 'Disc avg count err (Hz)'
    - Parse disc_avg_count_err and count_err_sum from renamed JSON fields
    - Reset new labels on disconnect
    [gpsdo_monitor.py]
2026-03-29 Monitor: update disc presets for count-error-in-Hz gain units
    - slow: i_gain 0.10 -> 2.0
    - normal: i_gain 0.20 -> 5.0 (matches config.h default)
    - fast: i_gain 0.40 -> 10.0
    [gpsdo_monitor.py]
2026-03-29 Make PLL1/PLL2 enable runtime-configurable with CE control and alarm exclusion
    - Replace compile-time ADF1_INSTALLED/ADF2_INSTALLED with runtime g_adf1Enabled/g_adf2Enabled
    - Add pll_ctrl JSON command for get/set of PLL enable state
    - Drive CE line low on disabled PLLs via adf.enable(false)
    - Disabled PLLs excluded from alarm logic and lock watchdog
    - Persist PLL enable state in DiscCtrlBlob v6 (EEPROM)
    - Add Enabled checkbox to PLL1/PLL2 boxes in monitor GUI
    - Grey out Set O/P and Registers buttons when PLL disabled
    - Virtual LEDs show grey for disabled PLLs
    - Save/Restore settings includes PLL enable state
    - Update capture script demo data and regenerate screenshots
    [config.h, gpsdo_monitor.py, main.cpp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]
2026-03-29 PCB catchup
    [Twin_PLL_GPSDO.brd, Twin_PLL_GPSDO.sch]
2026-03-29 Rename ADF1/ADF2 Lock to PLL1/PLL2 Lock in GUI virtual LEDs
2026-07-15 JLC Build, v 1.1
    [Twin_PLL_GPSDO-JLCPCB-BOM_v_1_1.xlsx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]
2026-08-01 First batch committed to JLC
    [Twin_PLL_GPSDO-JLCPCB-BOM_v_1_1.xlsx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]
2026-09-24 initial corrections to producion PCB
    [Twin_PLL_GPSDO.brd, Twin_PLL_GPSDO.sch]

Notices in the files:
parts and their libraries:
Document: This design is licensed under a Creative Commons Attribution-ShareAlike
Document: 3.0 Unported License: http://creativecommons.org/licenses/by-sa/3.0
